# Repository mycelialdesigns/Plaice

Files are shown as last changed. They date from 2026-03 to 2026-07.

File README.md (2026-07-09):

# Plaice
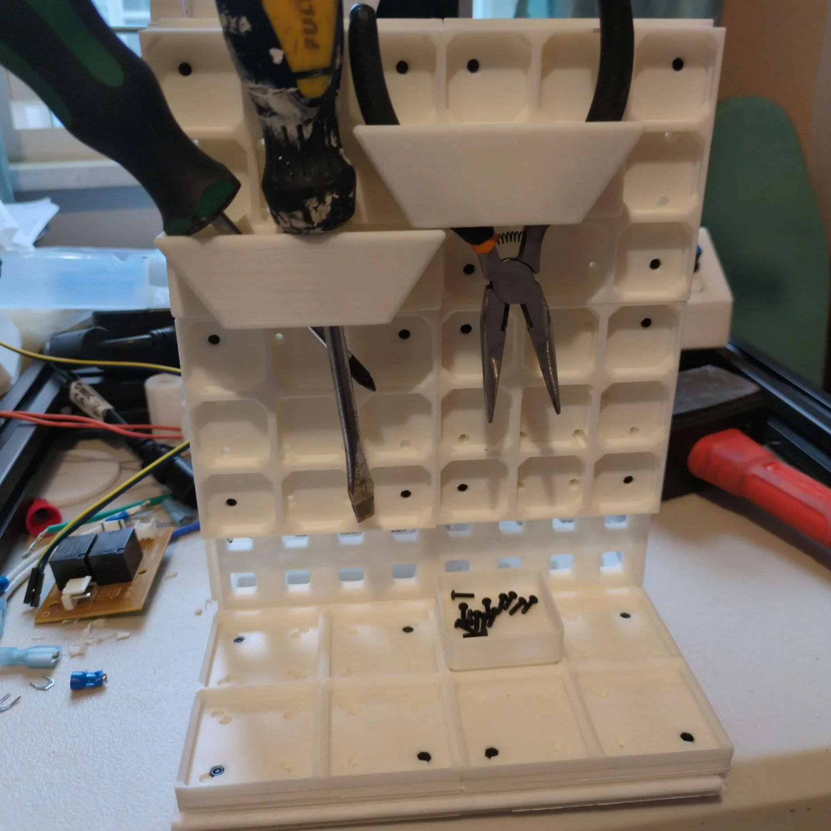
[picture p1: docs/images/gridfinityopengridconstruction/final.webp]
Gridfinity+OpenGrid Organizer
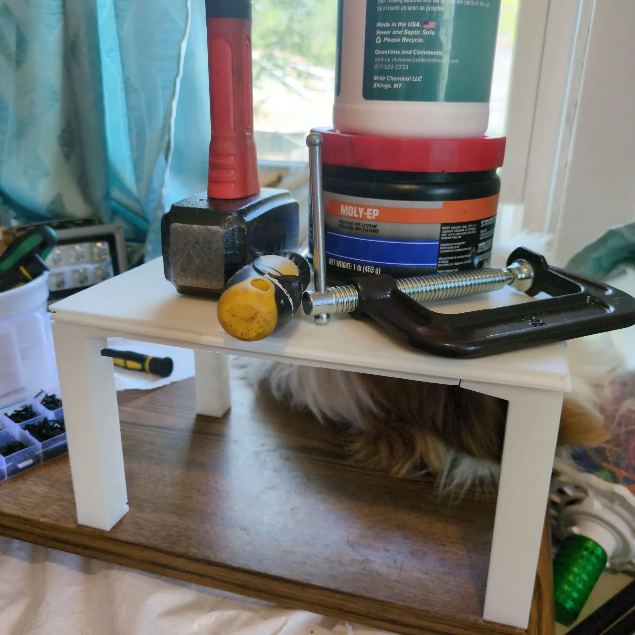
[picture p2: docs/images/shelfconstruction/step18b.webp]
Shelves
 

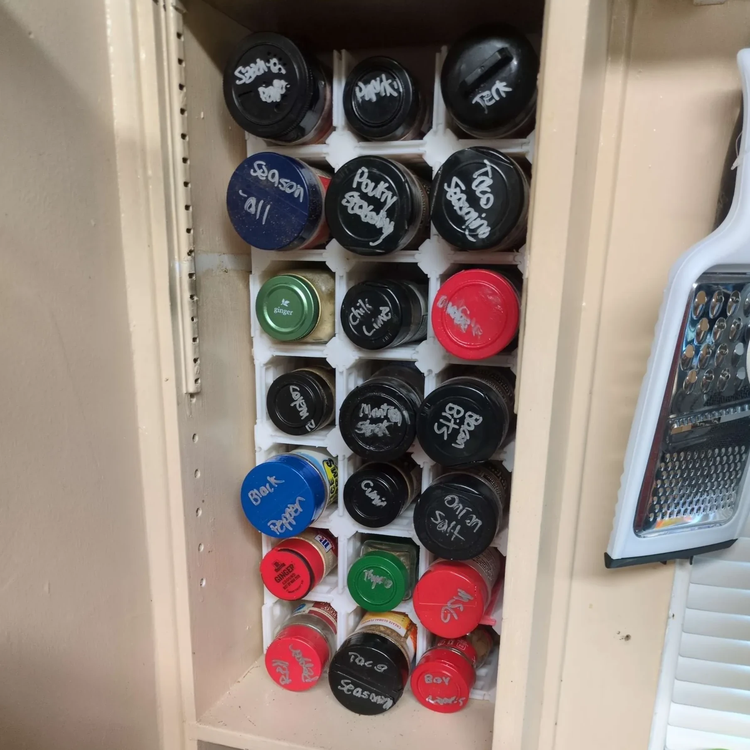
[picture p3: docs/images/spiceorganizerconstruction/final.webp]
Spice Organizer
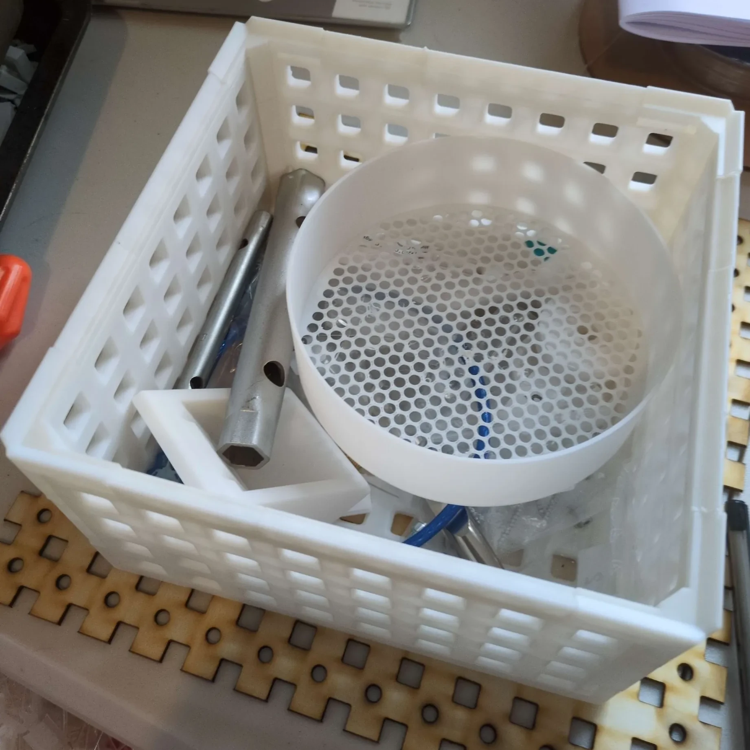
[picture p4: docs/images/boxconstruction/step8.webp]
Stacking Box
  

**_Print Once, Reconfigure as Your Space Evolves!_**

# What Is Plaice?
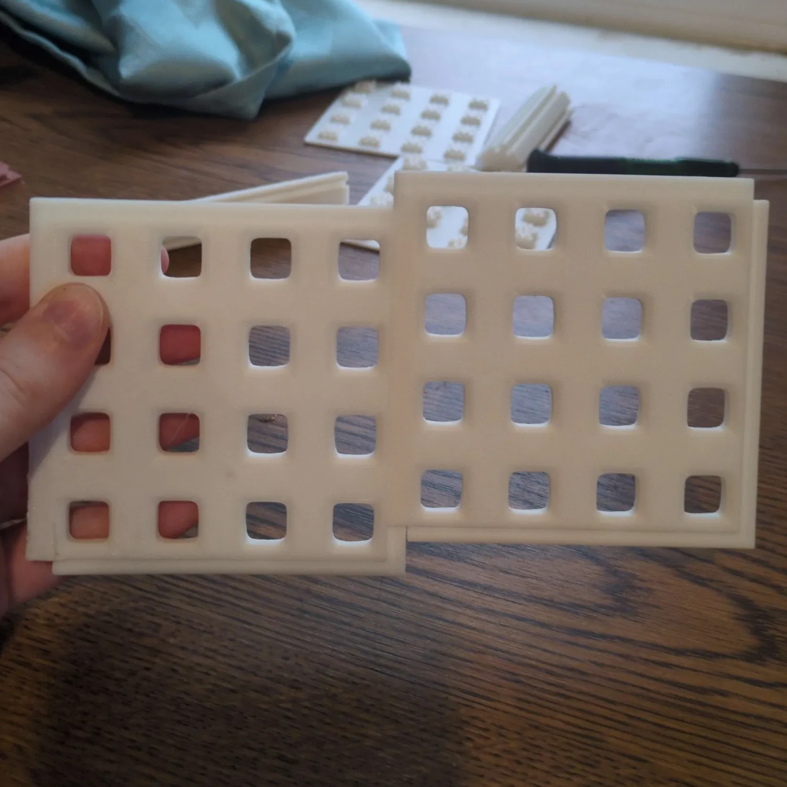
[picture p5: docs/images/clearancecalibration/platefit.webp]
Two plates slid together


Plaice is a 3d-printable modular construction system for living space organization. Unlike other similar
systems, Plaice enables radical free-form constructions out of basic structural elements called [_plates_](/docs/components/Plates.md),
which naturally slide together to allow for large assemblies to be built from smaller parts. Using just a few standard Plaice components,
it's possible to make:
- [Stacking Boxes](/docs/recipes/StackingBoxes.md)
- [Multi-tiered shelves](/docs/recipes/Shelves.md)
- [Spice Organizers](/docs/recipes/SpiceOrganizer.md)
- [Desktop Tool + Hardware Organizers](/docs/recipes/GridfinityOpenGrid.md)
- Drawers
- Hinged Clamshell Boxes
- Drawer Dividers

**_... among many, many more things!_**

Open, endlessly [remixable](/docs/design/InterfacingAndRemixing.md). Seamless compatibility with other systems
like [Gridfinity](/docs/components/GridfinityIntegration.md) and [OpenGrid](/docs/components/OpenGridIntegration.md). Plaice makes
your organization dreams a reality while allowing experimentation without waste through modular composition. 
Designed with simplicity and internal coherence in mind, Plaice stands out from similar "universal" organization
systems in its relatively small number thoughtful, carefully-engineered components.

_(Printing for most parts assumes settings for a .`4 mm` nozzle, two perimeters, and a layer height of `0.1 mm`. Most components will print without the need for slicer-generated supports, but check individual component pages for details.)_

**To get started with using Plaice**, first follow the [clearance calibration guide](/docs/recipes/ClearanceCalibration.md),
and then feel free to check out the other [recipes](/docs/recipes/Index.md).

---

### [Directory of all Plaice components](/docs/components/Index.md)

### [Directory of Plaice design articles](/docs/design/Index.md)

### [Contributor Guide](/CONTRIBUTING.md)

If you like this project, consider donating to the original creator at <https://paypal.me/MycelialDesigns>

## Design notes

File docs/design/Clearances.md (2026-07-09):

# Clearances
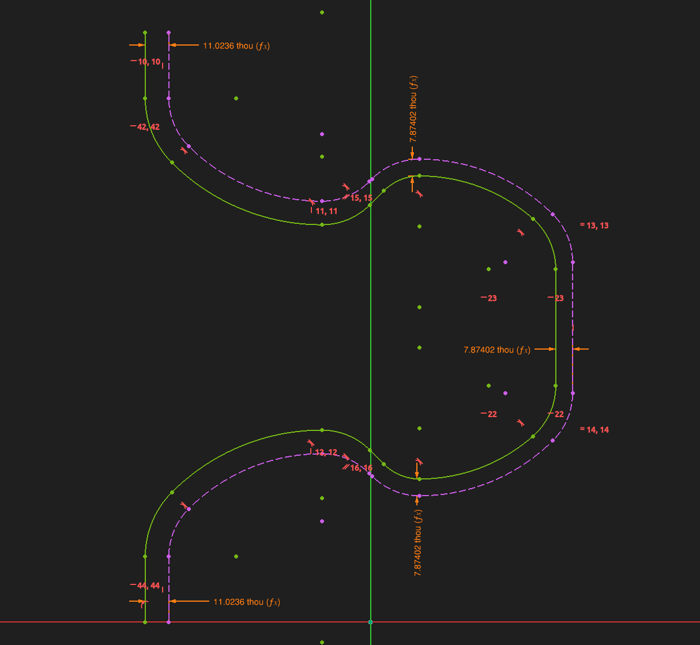
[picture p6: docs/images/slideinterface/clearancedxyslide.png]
Slide Interface, Clearanced For XY Printing
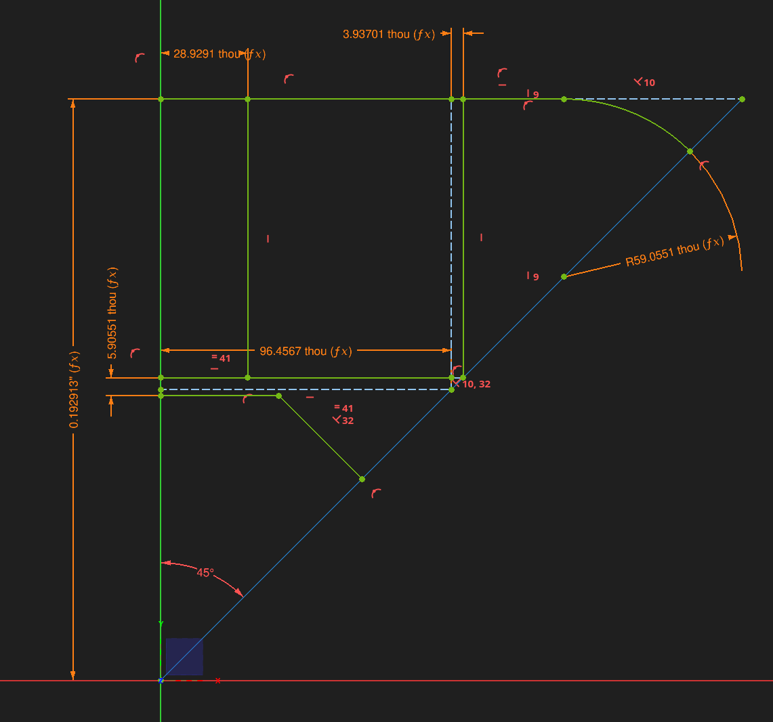
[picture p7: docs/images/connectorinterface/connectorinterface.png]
Connector Interface, Showing Tolerances
 

Designing Plaice components to fit together requires careful attention to the nominal clearances between components.

## Preliminary Definitions
Clearances describe the size of gaps between two surfaces so it's important to have a clear reference to what the surfaces
involved are. In our case, there are three different sources for relevant geometry to reference: "*interface*" geometry
which consists of 2D profiles in CAD expressing an idealized meeting-curve of two components, "*model*" component geometry which
represents the geometry expressed in 3D CAD and/or in exported .stl files, and "*de facto*" geometry which is the physical geometry
of real components after printing. 

## Print Bias Correction Clearances
Due to artifacts of the 3D printing process, de facto geometry will never exactly match model geometry. However, we have control
over the model geometry, which means that if we have systematic biases in how de facto geometry deviates from how we want it
to be, we can simply adjust the model geometry to compensate for those biases as best we can. The de facto geometry as we'd like it to
be is what we call *idealized* geometry, and it's essentially what we would get if we had a 3D printer with no printing artifacts whatsoever
and a layer height approaching zero (+ perfectly smooth). 

Consequently, our approach to creating modeling geometry can be kicked off by starting with the idealized geometry, and then introducing small tweaks
to the model geometry to correct for differences from the ideal which would occur when turned into de facto geometry via printing. These small tweaks
are all in the form of clearances applied between the idealized geometry and the modeling geometry at different locations throughout the model, and
so we call them *print correction clearances*. Typically, the additional clearance is applied where relevant to the geometry, and the surrounding
geometry has a smooth transition back to the uncorrected geometry where the corrections are not required.
It's important to note that these clearances are meant to be somewhat of a statistical average of the
clearance biases that they're meant to correct for across _all_ printed Plaice components, which says nothing of the variation, but we can simply
lump that in with other factors which determine our overall manufacturing tolerances.

### XY Hole Shrinkage Clearance
Slide Interface, Clearanced For XY Printing
When a 3d printer prints a circular arc in the XY plane, it deposits hot plastic centered along the arc which briefly
flows, then cools and hardens. Consider a simple model of this where the nozzle deposits plastic which falls in a region
bounded in XY by offsets of the arc, padded to the printing layer height. Also suppose that the volume of plastic deposited
on either side of the "nominal" arc that the nozzle follows is equal. Then, a direct consequence of these assumptions is that
the offset for the "interior" arc (smaller diameter) must be _larger_ than the offset for the "exterior" arc (larger diameter).

In other words, 3d-printed holes shrink along XY, with smaller 3d-printed holes systematically shrinking more than larger ones, and more
generally, any concave geometry along XY will expand inwards, with the amount of expansion dependent on curvature. While this effect
is not describable purely by a constant offset for _all_ radii of curvature, in practice, in Plaice, the curvatures of surfaces which
need an XY hole shrinkage clearance applied (mostly just [slides](/docs/design/SlideInterface.md)) are all pretty similar. We call the clearance value which issues
this modification to the design geometry over the idealized geometry the _XY Hole Shrinkage Clearance_. 

### Z Overhang Depression Clearance
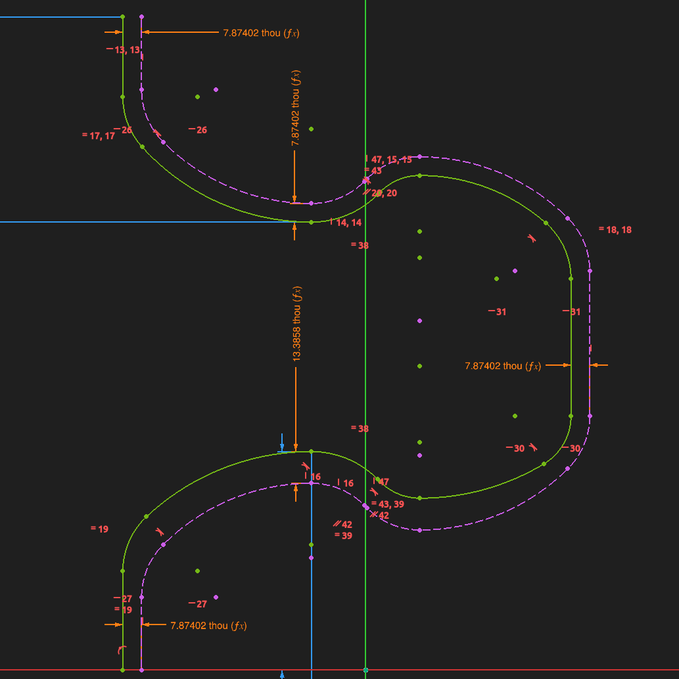
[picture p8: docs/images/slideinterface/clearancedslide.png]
Slide Interface, Clearanced For Z Printing

The overall process of 3D printing introduces some systematic errors which can make overhanging geometry depress along the Z axis toward the
build plate, both from physical causes and from the way that slicers interpret 3D designs. 

The single biggest physical cause has to do with
the fact that molten plastic will fall _down_ under the influence of gravity, and overhangs will tend to do the same unless cooled rapidly.
The same is true for _supported_ overhangs, because the support isn't completely solid, and may introduce bottom-surface roughness on removal.

To make matters worse, slicers determine what belongs on each layer "slice" of a model by intersecting the model with abstract planes which
are set to the height of the _top_ of the layer, not the middle, meaning that the effects of the semi-quantization induced by slicing will
cause overhanging geometry to shift _downwards_ by about half of a layer-height on average.

We cannot hope to model both factors exactly, but we can compensate by adding a clearance to "push up" any overhangs in the designs. We
call this applied clearance between the idealized and design geometry the _Z Overhang Depression Clearance_.

## The Clearance Multiplier
Print bias correction clearances aren't the only clearances we need to care about in the process of preparing Plaice components for printing.
Every 3D printer has its own quirks, and even when fully calibrated and printing geometry which corrects systematic printer biases,
individual 3d printers will still exhibit small variations in their output from print-to-print. 
Plaice components are designed to be printable by most 3d printers, and consequently, it's important that
we have some kind of mechanism for accommodating these dimensional variations. We do this by introducing additional clearances between mating parts
in a systematic way dependent upon how the parts are meant to mate. 

Plaice components like [plates](/docs/components/Plates.md) are highly dependent upon tight de facto clearances to minimize deflection in assemblies.
Simply choosing _one_ set of clearances intended for all printers would require us to select the _largest_ such clearance, which is
therefore unacceptable for our use-case. To resolve this problem, Plaice has a global _clearance multiplier_ which multiplies all non-print-bias-correcting
clearance values applied to design geometry. This multiplier is meant to be interpreted as approximately bounded below
by `1.0` (something intended for printers in the top 1% of print quality) and above by `1.75` (something which works for ~95% of all printers in the wild,
though it may wind up being a loose fit). 

## Clearance Levels
For .stl export of Plaice components, having a continuum of possible clearance multiplier values is untenable. To resolve this problem, we instead define
four clearance _levels_ for different values of the clearance multiplier, termed _Close_ for `1.0`, _Default_ for `1.25`, _Easy_ for `1.5`, and
_Forgiving_ for `1.75`. 

## Clearance Types
The "base" or "fundamental" clearance values which the clearance multiplier multiplies are assigned based on the intent behind mating geometry,
which falls into a small number of discrete categories we call "Clearance Types".

### Contact Fit Clearance
Applied to parts which are meant to assemble and _contact_ each other without substantial movement. Applicable to mating surface pairs where
assembly involves moving the surfaces toward each other, but also to mating surface pairs where the mating surface patches are small and/or compliant.
This is the tightest clearance type.

### Snug Slide Fit Clearance
Applied to mating surface pairs which have substantial contact surface area, and are meant to "slide" against each other, but only during
assembly.

### Smooth Slide Fit Clearance
Applied to mating surface pairs which have substantial contact surface area, but where the sliding between parts is meant to occur frequently
after assembly. This is the loosest clearance type.

## Tolerances
We mostly talked here about clearances instead of tolerances because most of the relevant tolerances to Plaice are actually one-sided tolerances
instead of symmetric tolerances. For example, for two [slides](/docs/design/SlideInterface.md) to fit together with _any_ other slides within
tolerance, they must have de facto geometry which never crosses the slide _interface_ which their idealized geometry is offset from. To bound the other side,
for each kind of interface, we do the simplest possible thing and declare that the idealized geometry with the maximum acceptable clearance multiplier is
the other surface defining the outer limit of the one-sided tolerance.

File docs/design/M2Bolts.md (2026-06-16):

# M2 Bolts
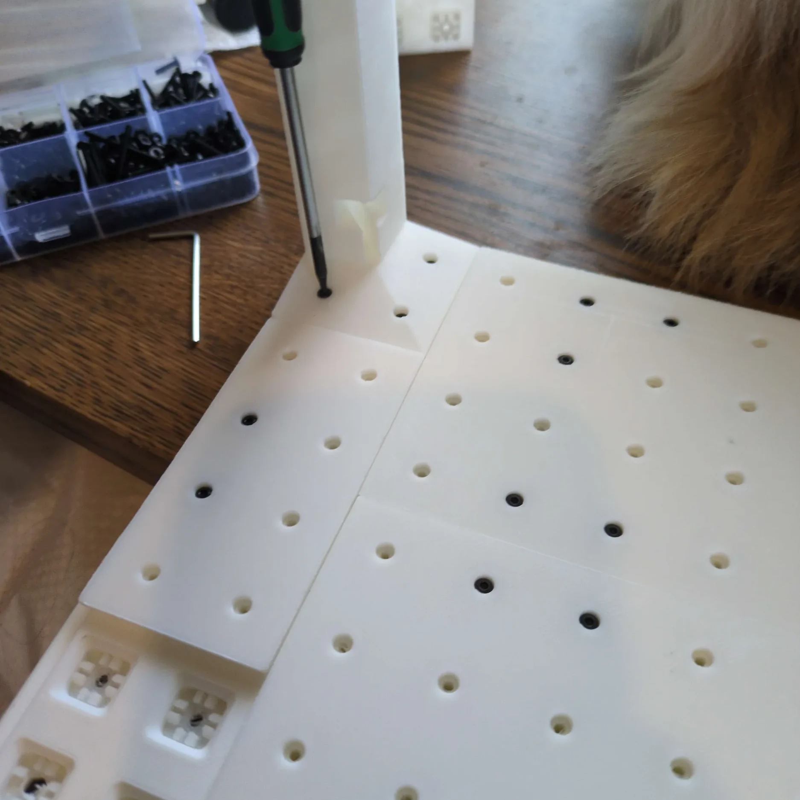
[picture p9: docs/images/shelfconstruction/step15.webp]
Nubbed covers secured on the bottom of a shelving unit


Plaice largely avoids the use of embedded hardware for the sake of rapid prototyping, but when it comes time to "cement" a design for a household organizer,
it can be advantageous to incorporate hardware for improving the strength of assemblies. (For a worked example of this,
see e.g: the [recipe for stacking shelves](/docs/recipes/Shelves.md)). Additionally, Plaice leverages hardware in
situations where printing a single part could be suboptimal in [bolt-on components](/docs/components/BoltOnComponents.md).

## Required Lengths
M2 hardware is employed in Plaice, and it's strongly recommended you buy a kit
of bolts which (at least) includes `4 mm`, `6 mm`, `10 mm`, `12 mm`, and `16 mm` lengths.

The following is a handy guide
to what lengths of M2 bolts are required for various scenarios.

### Corner Caps

[Corner caps](/docs/components/CornerCaps.md) are composed of two separate pieces which are meant to be connected
together with a `6 mm` M2 bolt.

### Backings onto Bolt-ons

To use bolt-on components in the most straightforward way, where they
are simply bolted on to a Plaice [backing](/docs/components/Backings.md) which provides
[connectors](/docs/components/ClipInterface.md), M2 nuts must be slid into the backing.
In this case, the following lengths of M2 bolts are inserted from the bolt-on side:

| | Nubbed Backing | Clipped Backing |
|--|:--:|:--:|
| **Bolt-On** | `4 mm` | `6 mm` |

### Bolt-ons, Nubbed and Clipped Connectors

Beyond the case of backing bolt-on components, M2 hardware can be employed in Plaice
to secure connections which would otherwise be accomplished purely through clip/nub connections. This attatchement provides more resistance to pull-out and some degree of preload. For example, Plaice clipped [covers](/docs/components/Covers.md)
may be attached to nubbed covers and secured with `6 mm` M2 bolts (together with captive M2 nuts).
We can generalize that rule to other components with clipped and nubbed connectors:
e.g: a nubbed [plug](/docs/components/Plugs.md) attached to a clipped plug _also_ can be secured with `6 mm` M2 bolts.

But clipped and nubbed connectors aren't the only things that can be on opposite ends (bolt head and nut end) of
a M2 bolt -- Bolt-on components atop backings may be at either of the ends. In these
situations, a single bolt should go through
end-to-end. In tabular form, here are the required lengths of bolts for every combination of two "ends":

| | Bolt-On  | Nubbed Connector | Clipped Connector |
|--|:--:|:--:|:--:|
| **Bolt-On** | `16 mm` | `10 mm`  | `12 mm` |
| **Nubbed Connector** | `10 mm` | -  | `6 mm` |
| **Clipped Connector** | `12 mm`  | `6 mm`  | - |

### Thru-Nubs

In a Plaice assembly involving thru-nubs, the required M2 bolt lengths may be derived from the table in the
previous section by adding `7 mm` (`1 HU`) for each (possibly chained) thru-nub, and then rounding up
to the nearest multiple of `2 mm`. This rounding is not _ strictly required_ if you have readily available bolts
 with the required dimensions, but M2 bolts 
in `2 mm`-multiple lengths are generally more likely to be stocked in stores. 

One particular case of this is worth calling out due to its frequency:
When connecting **two beams** (as one would for [building stacking shelves](/docs/recipes/Shelves.md)),
a nubbed connector from the top of one beam attaches to a thru-nub which then attaches to the
clipped connector at the bottom of the next tier's beam. From the table above, the base length
is then `6 mm`, and so `+ 7 mm = 13 mm`, or rounded, **`14 mm`**.

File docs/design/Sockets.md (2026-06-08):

# Sockets

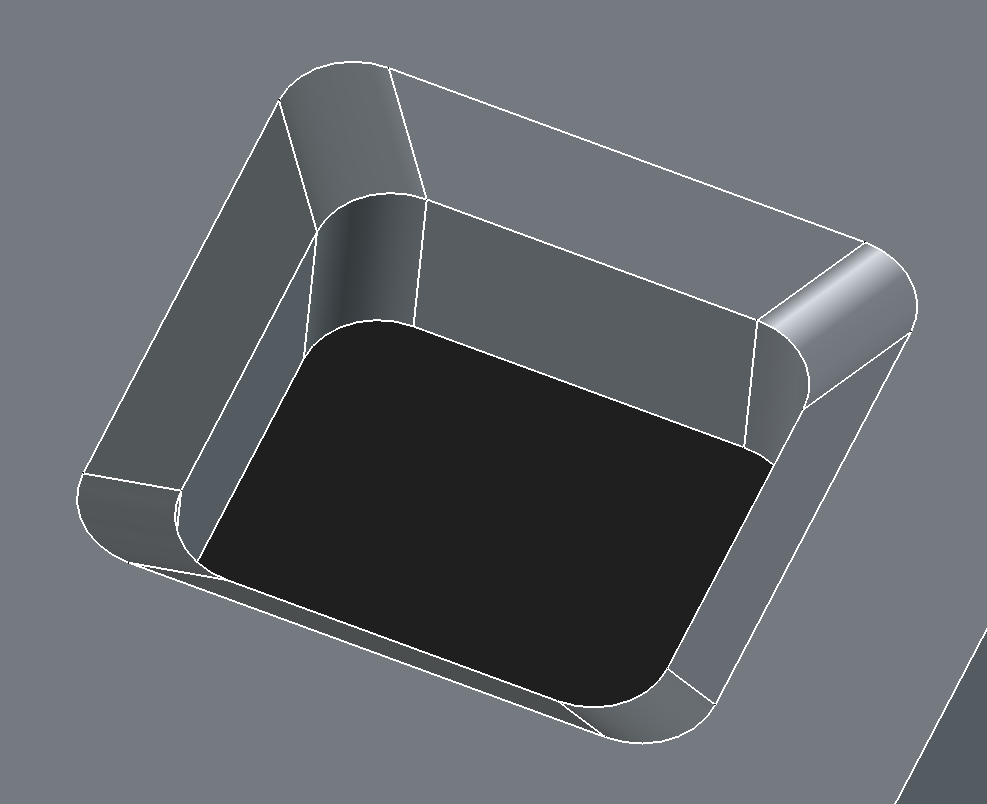
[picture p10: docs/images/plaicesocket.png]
A Plaice Socket
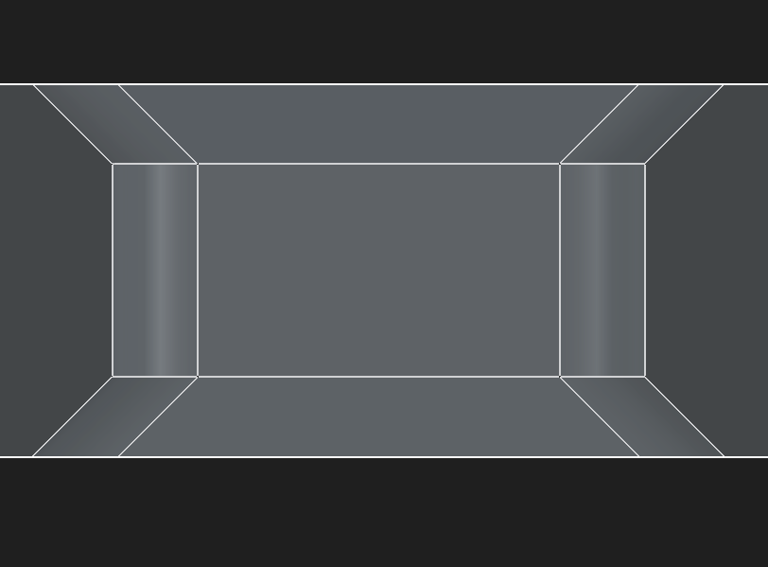
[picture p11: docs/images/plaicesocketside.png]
A Plaice Socket, Side View (See-Thru)


Plaice _Sockets_ are chamfered rounded-square voids which allow the insertion of Plaice [clipped and nubbed connectors](/docs/design/ClipInterface.md).
They have a [`1 HU`](/docs/design/Units.md) depth, with the leading `2 x 1.5 mm` devoted to 45-degree chamfered sections on each side. The remaining `4 mm` has a cross-section of
a rounded `10 mm` square with a corner fillet (radius of `1.6 mm`). 

## Strength and Deflection

Intuitively, since a Plaice [plate](/docs/components/Plates.md) is a slab with sockets cut out of it, the plate's strength heavily depends
on the socket dimensions. The deflection of a Plaice plate with sockets is roughly two times what the deflection of
what a solid plate would experience under a one-sided load, and around the de facto socket dimensions, FEM verifies that the deflection is roughly linear
in the socket width. Consequently, Plaice sockets are the smallest dimensions that they can be while maintaining the functionality
of socket connectors. 

## Print Correction Clearances

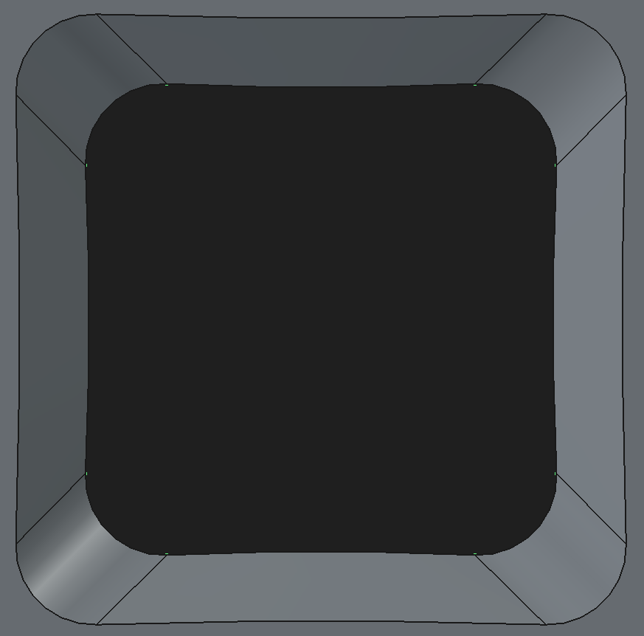
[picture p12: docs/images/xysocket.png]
A Plaice Socket, Corrected for XY Printing


When a socket is printed oriented along the XY plane, the internal radius shrinkage [print correction clearance](/docs/design/Clearances.md) applies, and so the modeled
CAD geometry needs to have larger fillet radii in the socket corners. However, the straight sides of the CAD geometry don't have an associated correction to apply!
Empirically, it appears to be the case that uncorrected sockets print with a slight mensicus shape along those nominally straight walls, almost as if they're "smoothing"
out the radius shrinkage correction from the filleted corners. To correct for this, the CAD geometry for XY sockets replaces the straight segments with arcs which
are constrained to be tangent with the (enlarged) corner fillets and also with the centers of each segment.

## Manufacturability

Sockets are explicitly designed to be manufacturable via subtractive manufacturing (routing). This is the reason for the corner fillets, as well as the particular
way that the socket is chamfered. The radius of the corner fillet does not change along the chamfer, which allows the fillet to be cut more cleanly
and efficiently by a single straight bit than if a changing fillet radius were used. The radius of the fillet is set so that a 1/8" diameter routing bit (US units)
could be used to cut sockets. The chamfer having a length smaller than the fillet radius also means that the chamfer can _also_ be cut smoothly using a 90-degree
V-carve bit, if desired.

Furthermore, the chamfer length's value of `1.5 mm` has direct implications for laser cutting, since `1.5 mm` wood veneers are not difficult to come by. While 3d printing
is still necessary in such a set-up to provide inserts for the chamfers, this dimensioning makes the approach viable.

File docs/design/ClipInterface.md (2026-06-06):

# Clipped and Nubbed Connectors
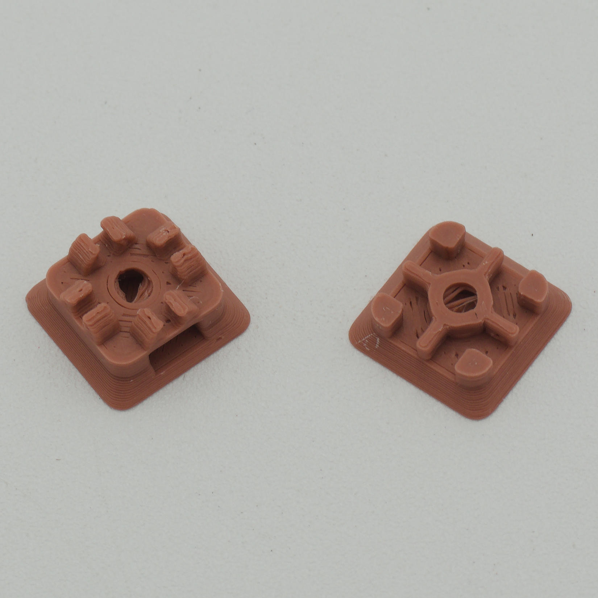
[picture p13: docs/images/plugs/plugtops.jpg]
Plugs, Clipped and Nubbed
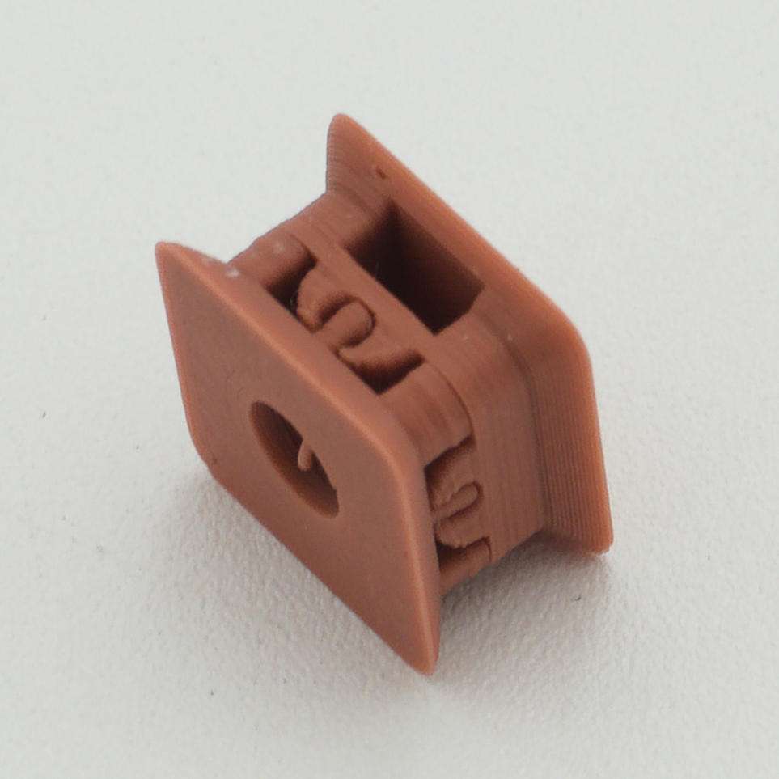
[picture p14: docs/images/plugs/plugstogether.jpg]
Plugs, Clipped and Nubbed Connected
 

Clipped and nubbed connector pairs provide a way to connect two Plaice components, most frequently inside of a Plaice [socket](/docs/design/Sockets.md).
They are "snap" (compliant) connectors where the four clips of a "clipped" connector grabs on to the four nubs of a "nubbed" connector,
preventing movement between the two halves unless the connection is undone through applied force to separate them. 

## Geometry

Connector interface, 1/8 of the top-down schematic

Clipped and nubbed connectors have a rounded square footprint which fits inside
of Plaice sockets. Both types of connectors share the same four-fold rotational symmetry about their center, with the eponymus "clips"
and "nubs" arranged along the edges of the rounded square base. For clipped connectors, that's all there is to the top-down layout,
but for nubbed connectors, there is additionally a central octagonal island and four corner islands. 

### Clip geometry
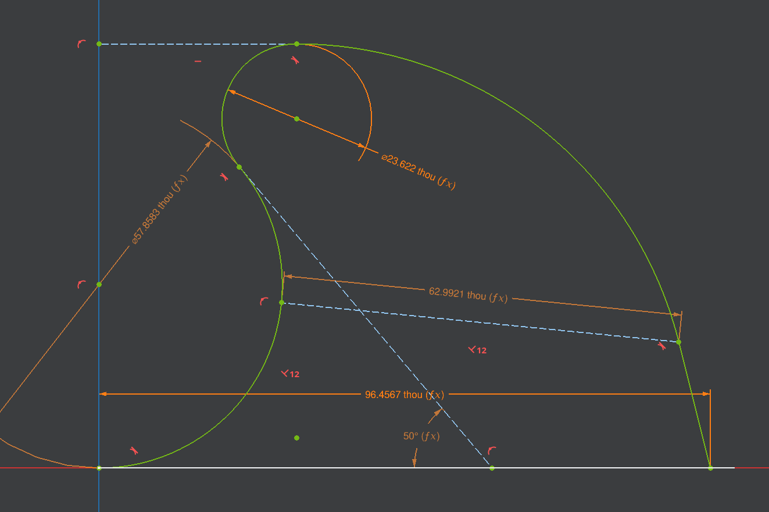
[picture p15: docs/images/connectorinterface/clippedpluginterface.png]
1/2 of a clip profile


The geometry of the clips is very carefully engineered for their small `~5.0 mm x ~2.3 mm` footprint to ensure that they won't break
under typical use (and then some). The clip prongs are tapered in such a way that it does not take many layers from
the tips of the clips to reach a width which is able to pack in two external perimeters, which allows the profile to mostly
behave like a bulk material. The profile of a clip prong is made of three arcs, one for the clip center, one for the tip of
the prong, and another for the outside envelope of the clip, with a line segment completing the connection to the base.
The top arc is constrained by a minimum size to allow for the 3d-printed clip prong tip to more smoothly slide against a paired
nub, and the angle of closure of the interior arc is also set to help the prong tip move out of the way when a nub is inserted.
The central arc's radius is maximized to spread out stresses encountered when the clip is bent, but the outer arc's geometry
(+ line segment) is largely set up for achieving the maximum number of perimeters as quickly as possible, since FEM results
indicate that stress does not tend to concentrate there. 

#### Clip FEM
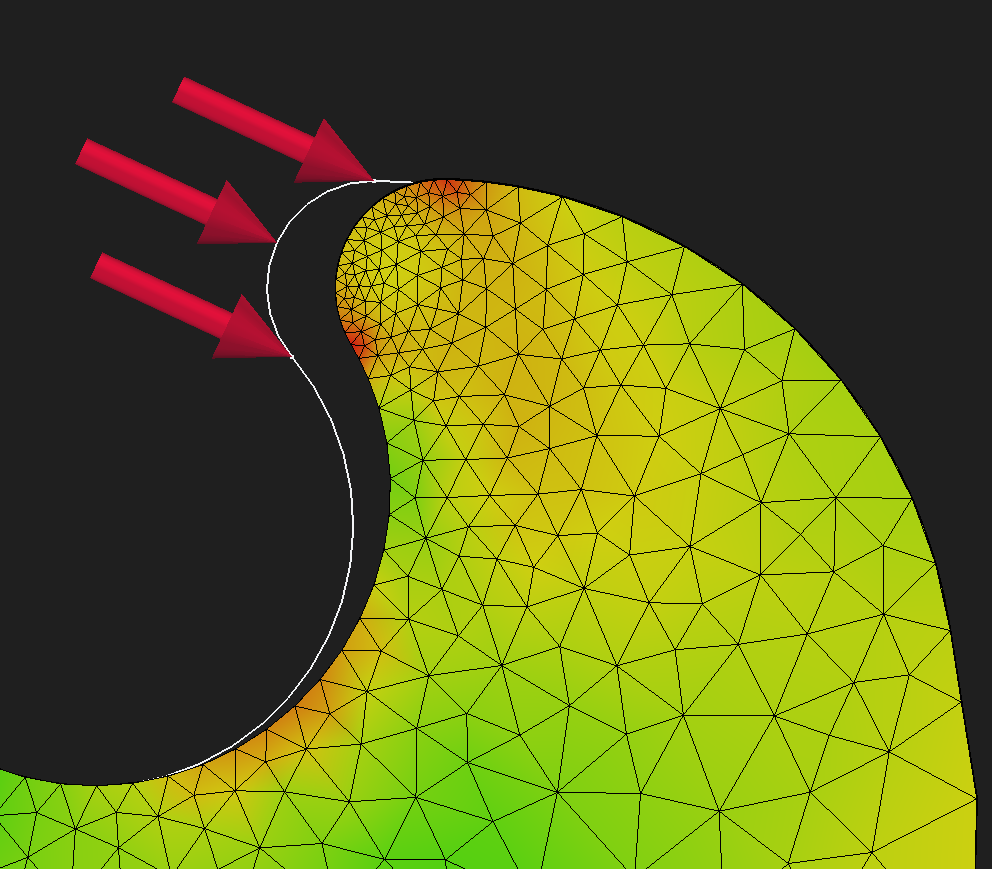
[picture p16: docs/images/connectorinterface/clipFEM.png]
FEM on a Clip w/ heatmap of Frobenius norm of strain tensor


To ensure that the compliant clips stay functional after repeated use, a finite element analysis of the strains experienced
by the clip when bent allows for optimization of the clip design. Additionally, for the clip geometry
as defined above, to bound the value of the base width of the clip, it's necessary to simulate what happens when the clip is deformed
during connection to ensure that the clip prongs never have any part of them extend beyond the base footprint, because it would cause
interference with the four corners of the paired nubbed connector.

To analyze the results of the FEM, unlike the situation with the [slide interface FEM](/docs/design/SlideInterface.md), the stresses experienced by the
clip during connection are transient. Consequently, a static analysis like what was implemented in FreeCAD for this will not
tell the whole picture, but we can still gain some insights. In particular, we are interested in the
strain experienced by the clip when bent to its "open" position, and want to minimize the maximum principal strain. Unfortunately,
FreeCAD has no built-in expression for principal strain, and finding principal strain using a component-based closed formula is fairly
unwieldy. However, we _can_ input a formula for the Frobenius norm of the strain tensor, which allows us to indirectly bound the
principal strain. 

### Nub Geometry
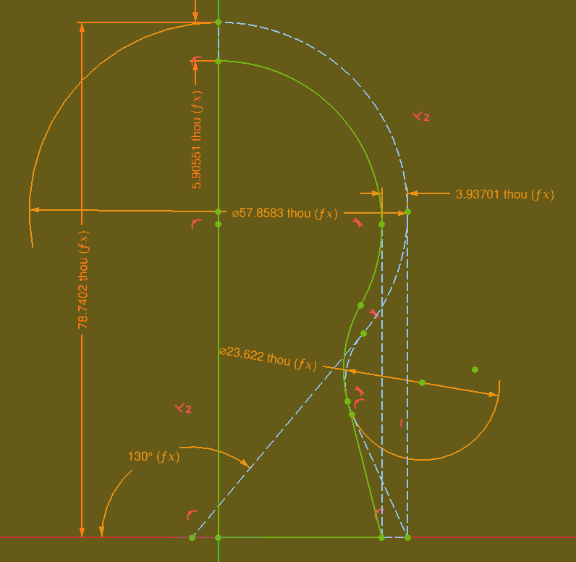
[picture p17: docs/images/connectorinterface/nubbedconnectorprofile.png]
1/2 of a nub profile


For the most part, the geometry of nubs is the inverse of that of clips, but the bottom of the nub is modified to connect
to the connector base with a straight line as opposed to an arc. This nub base is set up in such a way that the bottom of the nub
has exactly the same width as its maximum width up above. This is done to give extra clearance to the tips of connected
clips (to handle deformations under load), and also to create a clean visual transition to the seam with the central octagonal island.

## Clearances

For the top-down footprint, most clearances from the top-down "interface" profile are set to the generic "contact" clearance, since the
mating surface area is fairly small, and it's structurally important to prevent relative rotation of the connectors as much as possible.
However, there are some exceptions -- in particular, the central octagonal island on the nubbed connector is given more clearance from
the interface bounds, because the central island is not meant to engage with anything else, and is simply there to serve as a sheath
for inserted M2 bolts. 

The side profiles of the nub and the clip provide their own special cases. For the clip profile, no clearances whatsoever are applied,
because the clip is compliant, and having fixed geometry also greatly simplifies the analysis of the clip's strength. The nub does
have clearances applied, but with a larger clearance at the tip of the nub which gradually works its way toward tangency with the interface
as the profile approaches the point of contact with the clip tip. Once again, this is done because the clip is compliant, and so
the required clearance drops closer to the clip's tip.

Vertical clearance between paired connectors is set to seat at the "snug" slide-fit clearance. This is somewhat larger than the contact
fit clearance to ensure that the connectors will tend to have a small gap between them when assembled with plugs on opposing sides of a
Plaice socket. The gap allows for a bit of pre-load to be generated by tightened [M2 bolts](/docs/design/M2Bolts.md), if desired. Additionally, the gap allows for Plaice sockets
to have somewhat looser tolerances on their chamfers given the relaxed seating of connectors, especially since this is made bidirectional
through the fact that a clip can engage with a nub and still have some retaining force even if not fully inserted.

## Relation to Sockets

Clipped and nubbed connectors are designed to fit inside of Plaice sockets, but the height of the connectors is only half (`2.0 mm`) of the
central portion of a Plaice socket (`4.0 mm`), and so at first, it would seem like we're leaving extra space on the table. Even stranger,
clipped connectors in Plaice typically sit atop a `2.0 mm` rounded square pad, but nubbed connectors don't have this! What gives?

There are two primary reasons for this apparent asymmetry, and both are related to how the system can accommodate alternative
types of connections which don't rely upon the clip-and-nub geometry. First, the `2.0 mm` rounded square pad provides valuable
space for the clipped connectors to be able to accommodate a captive M2 nut, which would be virtually impossible without it.
Second, it allows "stub" connectors consisting just of a `2.0 mm` rounded square pad on a plug to mate with a nubbed plug.
While that may not seem useful at first, it does open the door to the possibility of _routed_ Plaice components
which would otherwise need clipped connectors. While the current iteration of this specification doesn't include it,
future iterations should.

There's another, more subtle, more structural reason. The positioning of the clips on the clipped connectors and the corner islands on the nubbed connectors is such that
they make contact with an enclosing socket, preventing rotation. Consequently, they are made to be as thick as they possibly can
be considering the limited footprint of the connectors, applied clearances, and other objectives and constraints related to clip
geometry. Even after all that, the clip (being compliant) is still a seeming target for accidental breakage.
However, in the case of the clip geometry, the aforementioned `2.0 mm` rounded square pad helps to ensure that the clip
itself does not bear the brunt of the torque-induced stresses when inserted into a socket.

## Standard Orientation

By default, when considering horizontal Plaice [plates](/docs/components/Plates.md), it's typical to assume that the top side of the plate is for inserting clipped connectors,
and the bottom half is where components with nubbed connectors get inserted. The reasoning for this is based upon the geometry of [beams](/docs/components/Beams.md):
The bottom of a beam needs to be able to sit flat on a surface. Consequently, the bottom of a beam cannot protrude, as would be required
for a nubbed connector to reach the correct mating depth, and so it instead has a clipped connector embedded in a socket at the bottom and a nubbed
connector on top. Consistency with beam orientation is important for shelves, because it determines what can be mounted to the top surface of the shelf,
and generally, that includes all sorts of things, like [Gridfinity baseplates](/docs/components/GridfinityIntegration.md).
Conversely, the bottom side of a Plaice plate is a good place for e.g: Gridfinity mounts by analogous reasoning.

## M2 Bolt Usage
Clipped connectors typically have a channel on their side for the insertion of a M2 hex nut. When fully inserted, the nut is held
captive against some backing walls, preventing rotation. A hole on the front face of the clipped connector allows access to the
nut from external [M2 bolts](/docs/design/M2Bolts.md). 

Conversely, nubbed connectors make some provision for an M2 bolt to be inserted through their back face, with the shaft of the
bolt coming through a hole on the front face.

When the two halves are connected together via an M2 bolt/nut pair, the snap effectively cannot be separated unless the
M2 connection is undone, which can have many practical structural purposes in Plaice assemblies. At the same time, it is important
to realize that adding M2s is not a silver bullet -- an assembly can still be structurally weak even if all snaps have M2s.

## Printability Modifications
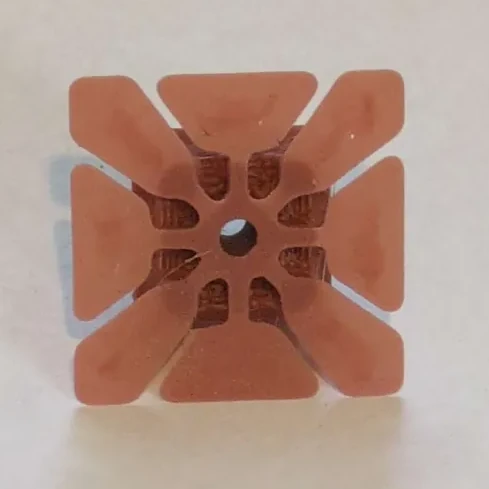
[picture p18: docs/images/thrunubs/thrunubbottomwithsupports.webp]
Thru-nub Bottom, Showing Mouse Ears
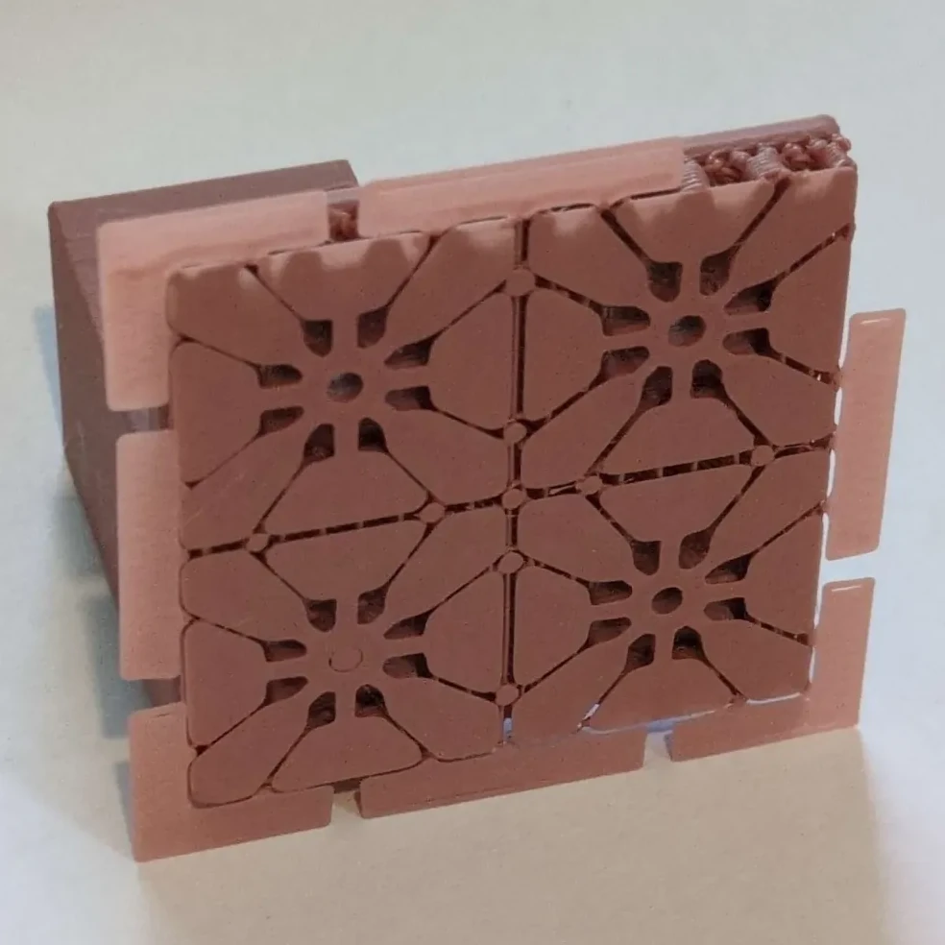
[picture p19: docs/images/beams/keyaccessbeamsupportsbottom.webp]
Key-access beam, showing supports on bottom
 

The print orientation of clipped and nubbed connectors is almost always such that their front and back faces align with the +-Z
printer axis, because typically they are printed in arrays on Plaice components which are intended to affix the component
to a Plaice plate, and so it generally makes sense to align the XY printer plane and the plane of these arrays. However,
this raises a problem for components (e.g: [thru-nubs](/docs/components/ThruNub.md), [beams](/docs/components/Beams.md)) which have clip or nub connectors on opposing sides:
Which connector should be on the bottom (and consequently, require some support and/or support removal, and possibly experience
some surface deformations due to sagging), and which should be on the top? Intuition would say that the clipped connector
is more intricate, and with more delicate features (compliant clips), and so it should belong on top.

Consequently, it's worthwhile to consider ways to "bake in" support structures for nubbed connectors oriented facing downwards
on the print bed to improve print quality, first layer adhesion, and the ease of support removal. Luckily, the geometry
of the nubbed connector makes it relatively easy to do so. Assuming that the tips of the nubs and all four corners have
good bed adhesion, bridging between them is a piece of cake given the involved dimensions. However, by default, they
don't have good bed adhesion. To improve this, an eight-petaled contiguous shape is formed on the first layer
to provide "mouse ears" for the first layer. This dramatically improves adhesion, and consequently
allows nubbed connectors to be printed upside-down without generated support structures.

There is no such similar printability modification for clipped connectors. This is for two primary reasons:
Firstly, due to the printability modification for nubbed connectors, the same kind of modification for clipped
connectors is largely unnecessary, since it results in the face of most clipped connectors facing upwards (+Z)
in print orientation. Secondly, the geometry of the clip connectors would require support structures to be
generated at the four corners of its layout, because unlike nubbed connectors, there is nothing in the corners on
the bottom printed layers for the base of the connector to bridge from. While that problem isn't insurmountable,
its inconvenience and low probability of use mean that it is currently unimplemented in Plaice.

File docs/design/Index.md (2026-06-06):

# Design Index

## [Bolt-on Components](/docs/design/BoltOnComponents.md)
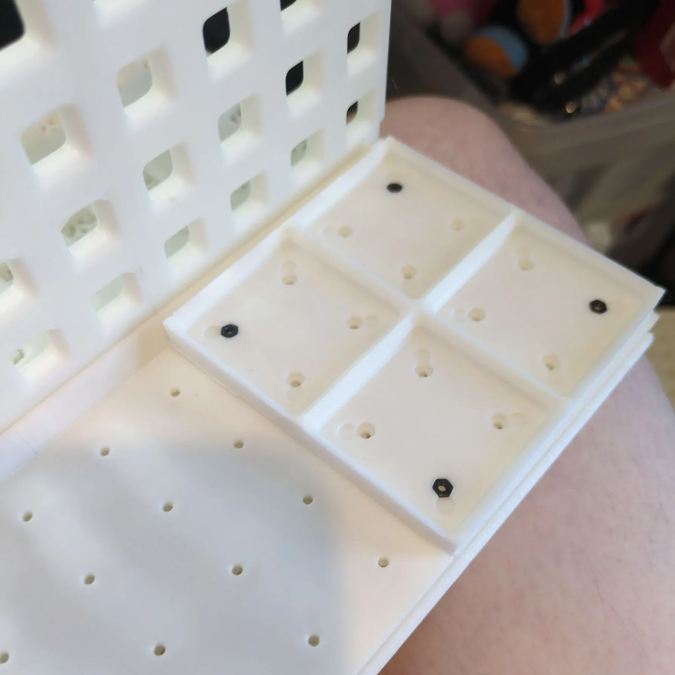
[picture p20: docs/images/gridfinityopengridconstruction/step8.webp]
A gridfinity bolt-on in the process of being secured to a clipped backing


## [Clearances](/docs/design/Clearances.md)
Slide Interface, Clearanced For XY Printing Connector Interface, Showing Tolerances

## [Clip Interface](/docs/design/ClipInterface.md)
Plugs, Clipped and Nubbed Plugs, Clipped and Nubbed Connected

## [Interfacing, Remixing and Licensing](/docs/design/InterfacingAndRemixing.md)

## [M2 Bolts](/docs/design/M2Bolts.md)
Nubbed covers secured on the bottom of a shelving unit

## [Slide Interface](/docs/design/SlideInterface.md)
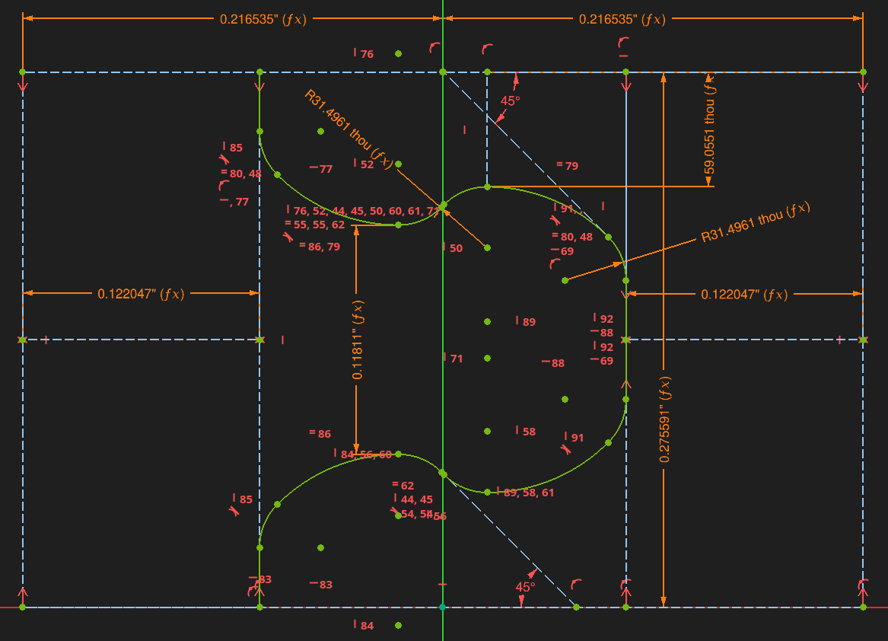
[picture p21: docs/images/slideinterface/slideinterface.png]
Slide Interface


## [Sockets](/docs/design/Sockets.md)
A Plaice SocketA Plaice Socket, Side View (See-Thru)

## [Units](/docs/design/Units.md)
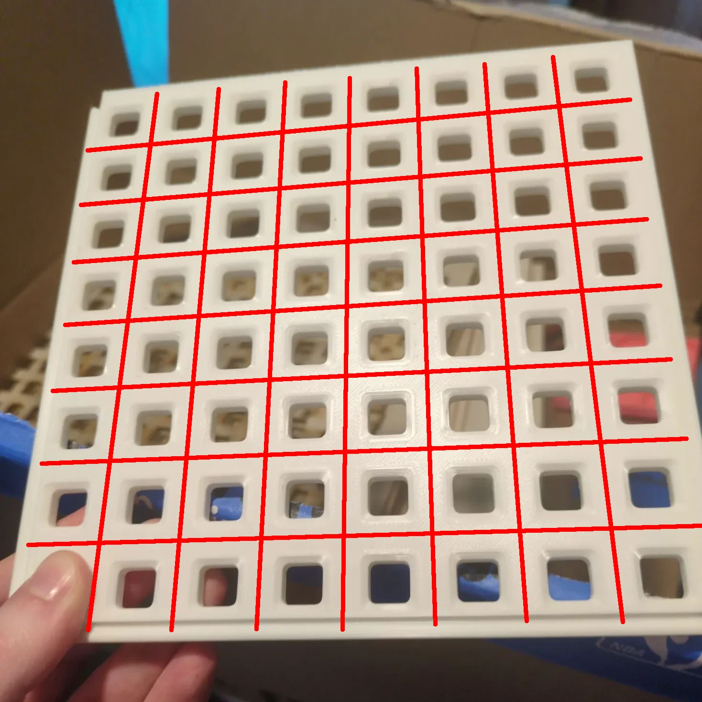
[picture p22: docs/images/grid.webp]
Plaice Plate Annotated with Cell Grid
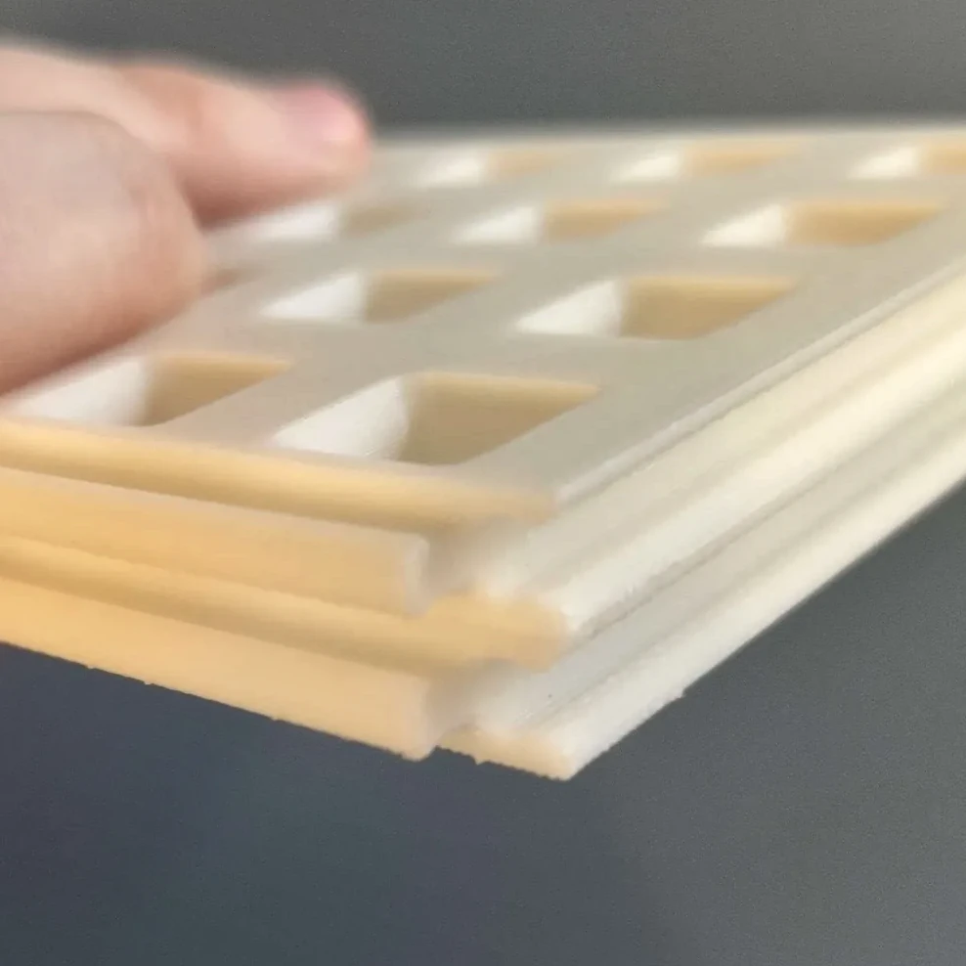
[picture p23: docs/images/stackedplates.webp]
Two Plaice plates, stacked


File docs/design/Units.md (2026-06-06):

# Units
Plaice Plate Annotated with Cell Grid Two Plaice plates, stacked

Any modular constuction system is faced with the fundamental problem of defining how the system
will sit in 3D space, and Plaice is no exception. Systems like [Ikea SKADIS](https://www.ikea.com/us/en/cat/skadis-series-37813/), 
[HSW](https://www.printables.com/model/152592-honeycomb-storage-wall), and [OpenGrid](https://www.opengrid.world/) are
two-dimensional mounting systems, which Plaice also provides as a sub-system.
That said, Plaice has more similarities with three-dimensional grid-based systems like [Gridfinity](https://gridfinity.xyz/) and `8 mm` stud systems ([MegaBloks](https://themegabloks.com/), [LEGO](https://www.lego.com/)). 
Unlike those systems, Plaice [plates](/docs/components/Plates.md) may occur oriented parallel
to any axis-aligned plane -- there is no "preferred" orientation for components of the system
(like how Gridfinity bins are always oriented "right-side-up"), even if there is a direction
(Z) which goes with gravity. While we could explain the dimensional unit system from an absolute
frame of reference (with plenty of reference to "quarter height-units" and rotational symmetries),
it's much simpler in practice to examine frames of reference taken relative to the orientation
of a Plaice plate that we intend to focus on. By convention, we take the [socket](/docs/design/Sockets.md) grid
to coincide with the XY plane when considering this plate-relative reference frame.

## Cell Units (CU)
Plaice Plate Annotated with Cell Grid

Along the XY plane, a Plaice plate is made of repeating square units known as _cells_. Each cell has a socket
placed squarely in the middle, and when projected onto the XY plane, each cell measures `21 mm x 21 mm`. Due to the centrality
of Plaice plates to the system, a length of 21mm is known as a **Cell Unit** (CU). Plaice plates are typically denoted by their
width and length in cell units, e.g: `2 x 4`, `4 x 4`, `8 x 8`, etc.

### Interoperability 

The size of a unit cell has massive implications for how easy or difficult it is to integrate
Plaice with other modular construction systems in a bidirectional manner. In particular, the `21 mm` "Cell Unit" length was chosen
for ease of integrating with [Gridfinity](/docs/components/GridfinityIntegration.md) (1:2 ratio in each side length for a unit cell)
and [OpenGrid](/docs/components/OpenGridIntegration.md) (4:3 ratio), as these are two of the most widely-used 3d-printed modular construction systems.
If two systems have unit cells of lengths `a` and `b`, then
the total length it takes for the two systems to "sync up" at a shared unit-cell boundary is given by their least-common-multiple, `lcm(a, b)`. 

Such synchronization (within a reasonable (read: printable!) length) is arguably a _requirement_ for a good bidirectional integration
because it takes any guesswork out of the systems' relative alignment. However, if we consider instead _unidiectional_
integations, where one system is used "in the large" and the other is used "in the small" (e.g: the user primarily uses system A,
but there are tiny pockets adapted locally to system B), there is no longer any such
requirement for strict synchronization, because portions that use the "smaller" system can simply give up some margin to be able to synchronize with system A again.
Such a strategy could be used to integrate Plaice as the "smaller" system relative to [Multiboard](https://multibuild.io/) and other systems for which
bidirectional integrations would be unwieldy. At the time of writing, no such unidirectional integrations have been implemented.

## Height Units (HU)
Two Plaice plates, stacked

Along the Z axis, a Plaice plate is `7 mm` thick. A distance of `7 mm` is known as a **Height Unit** (HU), and it also appears frequently in Plaice
definitions. This value is identical to a Gridfinity "height unit", though largely by coincidence. From divisibility principles mentioned in the previous section,
and due to the potentially-arbitrary orientation of Plaice plates in space, the thickness of a Plaice plate should evenly divide a grid unit. 21=7*3, and 3mm
is far too thin, so 7mm it is. 

3 HU being equal to 1 CU is exploited constantly in the design of Plaice components, since a plate placed on its side standing in the (lateral) "center" of a cell
then has exactly 1HU on each side of it as margin to the adjacent cells on the baseplate. For examples, see [corners](/docs/components/Corners.md),
[crosses and tees](/docs/components/CrossesAndTees.md), and [slide clips](/docs/components/SlideClips.md). 

## Fractional Units

If you read between the lines of the previous section and the symmetries of Plaice [slides](/docs/design/SlideInterface.md), you can deduce that
half of a height unit is an occasionally important quantity when discussing Plaice. Additionally, an even smaller fraction of a height unit, `.25 HU`,
is invoked for Plaice [covers](/docs/components/Covers.md).

## Base-2 Radix

To minimize the effects of tolerance stack-up and cumulative deflection, Plaice plates typically are only made with power-of-two grid-unit widths and lengths.
Any length and width of composite plate may be obtained by sliding Plaice plates together (optionally stabilising them against deflection using paired covers),
and obtainabile within a number of Plaice plates which is asymptotically logarithmic in the demanded dimensions.

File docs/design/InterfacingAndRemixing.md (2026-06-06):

# Interfacing, Remixing, and Licensing

Plaice is an open ecosystem where anyone with 3d modeling experience can contribute.
Beyond that, it is intended to be an ecosystem which inspires a culture of remixing and shared learning.

## Licensing

To support these goals, Plaice employs two separate licenses to different kinds of artifacts: the 
[CERN-OHL-S](/LICENSE-cern_ohl_s_v2.txt) to all CAD files, and [CC-BY-SA](LICENSE-cc-by-sa-4_0.txt) to everything else in this repository and its associated exports,
including 3d model files. 

The OHL-S is a "strongly reciprocal" license, meaning that any released CAD files or other
released files which use Plaice's CAD files must share the preferred form of the source file for making modifications,
which is most often the derivative CAD file(s) in question. In adopting the license for CAD files, Plaice intends
to prevent the scenario of a designer privately holding on to a CAD file, and only releasing `.stl`s for public
consumption due to some ulterior motive (possibly, but not necessarily commercialization-related.) Plaice
_does not care_ if the designs are mass-printed and sold, but the project _does_ care about ensuring that
designers and consumers are on equal footing. If Plaice is part of somebody's path to becoming
a maker, that path should have as little resistance as possible.

CC-BY-SA is adopted for all other artifacts (including 3d models) as a pragmatic lowering to the case
where it doesn't make sense to reference an original source as in the OHL-S. The attribution and share-alike
components ensure that the ecosystem of derived files remains open to remixing, and that remixes all have
an unbroken chain of attribution. Both are crucial to the kind of ecosystem that Plaice intends to cultivate.

## How-To
There are multiple different ways to create new components for Plaice or to remix existing components,
each with their own tradeoffs: (1) Bolt-on Parts, (2) CAD derivatives, (3) STL Modifications.

### 1. Low Friction, Low Customizability: Bolt-On Parts

By far the easiest and most-preferred way to integrate with Plaice is to bolting printed parts on to
a Plaice [clipped or nubbed backing](/docs/components/Backings.md), as described in more detail on the [dedicated page](/docs/design/BoltOnComponents.md).
While this is low-friction for the designer, and is completely agnostic to choice
of technoogies, it only generally applies to components which only seek to integrate with the
[connector](/docs/design/ClipInterface.md)-and-[socket](/docs/design/Sockets.md) portion of Plaice.

### 2. Medium Friction, High Customizability: CAD Derivatives

The next-preferred way to integrate with Plaice is to leverage the FreeCAD files made available in this repository.
Parts in those files use a hybrid of referencing a spreadsheet (`sheet.FCStd`) for "Plaice global" values which define
the system, and copy-on-change linked objects with custom properties (see, e.g: [MangoJelly](https://www.patreon.com/mangojellysolutions)'s [video](https://www.youtube.com/watch?v=9mohplbz7Wg) about the topic) for values which
define the configurations of components. To use them, create a copy of the CAD directory from this repo, and
add new FreeCAD file(s) devoted to your design which reference the base Plaice system files, or modify the Plaice
system CAD files directly. Once you are finished with design, optionally export models of your component(s) at the different standard
clearance levels, and upload 'em somewhere together with any CAD files that you created, used or modified which depend on
Plaice components.

### 3. Medium-High Friction, High Customizability: STL Modifications

3D-printing has an extensive `.stl` remix culture, so it's important that Plaice supports the workflow.
However, in Plaice, the [clearances](/docs/design/Clearances.md) applied to connectors and slides are _meaningful_. There are good
structural reasons for individual users of the system to want to minimize those clearances, tuning
the system to their own printer. That means non-parametric 3d models are in a bit of a difficult
spot -- while they can be remixed, providing all standard clearance levels would require creating multiple
different copies of those models. That's somewhat of a pain! To partially settle this,
in the case of direct 3D model remixes, Plaice parts in the so-called "standard" clearance level are the preferred
source for edits.

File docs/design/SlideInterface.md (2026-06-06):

# Slide Interface
Slide Interface

Slide connections allow Plaice components to join in a way which leaves only one degree of freedom unconstrained. The _slide interface_
is the curve ("profile") projected on the plane normal to the degree of freedom which is sandwiched between an idealized
"perfect" protruding and intruding slide.

## Geometry

The Plaice slide interface profile draws on inspiration from jigsaw puzzle pieces and woodworking dovetails, but with its
shape optimized for strength. It's designed so that when connecting
two Plaice [plates](/docs/components/Plates.md) along a span supported at both ends, the slides will not break when a heavy weight is applied.

By itself, the need for strength does not completely define the interface profile. It becomes a bit more explainable when combined with the following other requirements:
- Leave at least `0.8 mm` (two perimeters with a `0.4 mm` nozzle) of material between a plate's [socket](/docs/design/Sockets.md)-chamfer and the slide profile. 
- Use simple geometric primitives (arcs and line segments)
- Ensure all arcs have greater than some minimum diameter (`0.8 mm`) to ensure smoothness in real prints.
- Prevent the two halves of a slide from seperating even under the largest clearance between slides employed by Plaice, without substantial force.

### Symmetries

Even with the listed geometric requirements, the shape is still fairly underspecified. To put the interface's shape into sharper focus,
we'll need to explicate what kinds of geometric symmetries are desirable.

There are two major symmetries which apply to the slide interface. Both are kinds of mirror symmetry, but
with different motivations: Ease of Assembly and Strength.

#### Ease of Assembly: Vertical Flip Symmetry

When putting two Plaice plates together with slides, assuming that a protruding and intruding slide are properly paired, the two plates
should fit together without needing to adjust their orientations. By ensuring that plates don't need to
be flipped to match orientations, the cognitive load (and hence, time) involved in putting together a Plaice assembly
is reduced. Namely, this means ensuring a vertical flip symmetry across a central horizontal axis.

#### Asymptotic Strength Under Plate Stacking
Slide Interface, Tessellated Slide Interface, Tessellated Slide Interface, Tessellated Slide Interface, Tessellated </div>

Stacked Plates

There are situations where '7mm' (HU) thick 3d-printed PLA plates just aren't going to cut it for a given loading.
In those situations, it's reasonable to want to stack plates on top of each other, and secure them to form a larger composite.
This option is readily available through the use of [thru-nubs](/docs/components/ThruNub.md) and [plugs](/docs/components/Plugs.md).

Now, consider what happens when a stack of plates with identical orientations is connected to another stack of plates
using slides -- schematically, the result looks something like the line-drawing above.

To minimize the maximal stress under an applied load, it is beneficial to spread the induced stresses
over the largest possible area. One natural way to do this for the situation of the stacked plates is to ensure
each stack should take a similar cumulative stress. There isn't a simple way to apply that
criterion verbatim, but we can do the next best thing: We can ensure that the _roles_ of each stack are the same in relation
to each other.

To do this, all we need to do is to ensure that between every two stacked protrusions, there's an intrusion formed, and
between every two stacked intrusions, there's a protrusion formed. This is another kind of mirror symmetry.

## FEM Optimization

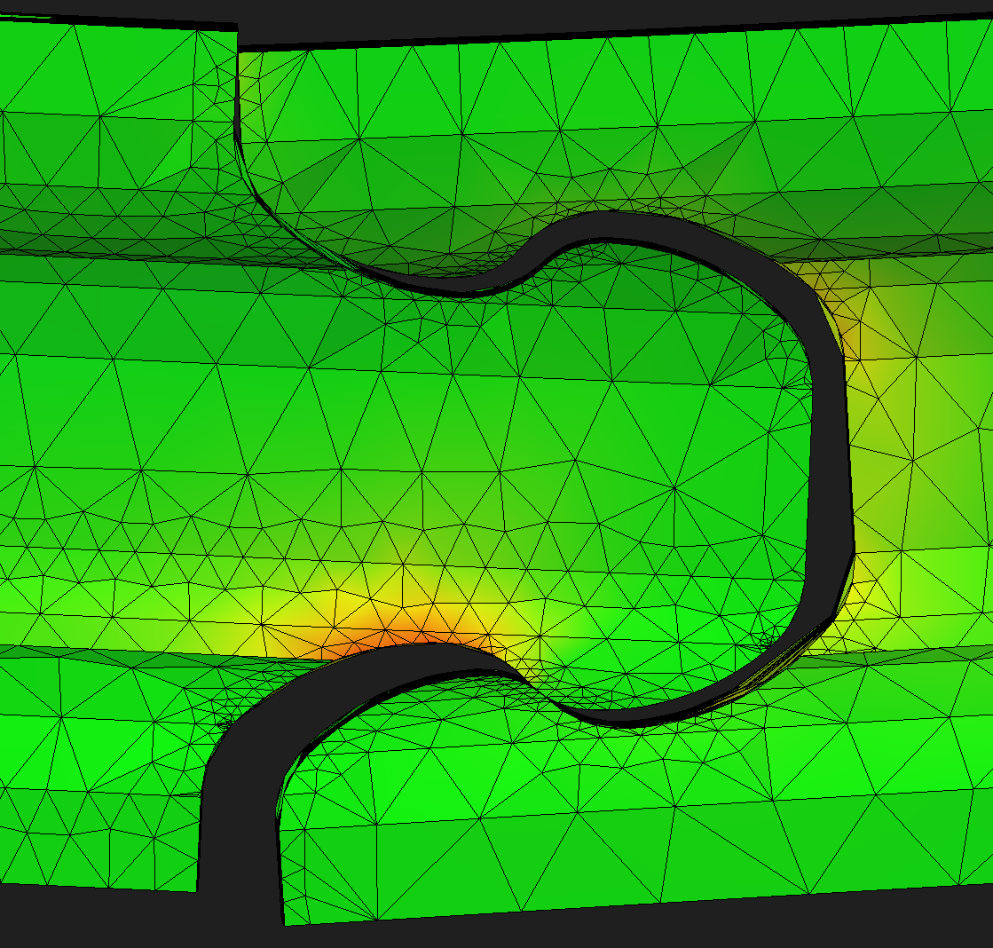
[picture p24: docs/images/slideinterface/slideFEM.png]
Slide FEM, Heatmap of Maximum Principal Stress


After the constraints mentioned in the previous section have been applied, the final shape of the Plaice slide interface is obtained
by performing hill-climbing on the maximal stress minimization objective. In particular, since the
objective assumes static loading, and PLA is dramatically stronger under compression than under tension, we can apply the Mohr-Coulomb yield
criterion and use the (max of the) maximum principal stress as a proxy for how close to yielding our parts are. 

## Clearances and Manufacturing Notes

For the slides to fit together, there needs to be some amount of clearance between protruding and intruding slides. Additionally, process-specific (3d printing)
biases need to be corrected for. See [the dedicated design page on clearances](/docs/design/Clearances.md).

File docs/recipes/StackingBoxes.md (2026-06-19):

# Recipe: Stacking Boxes

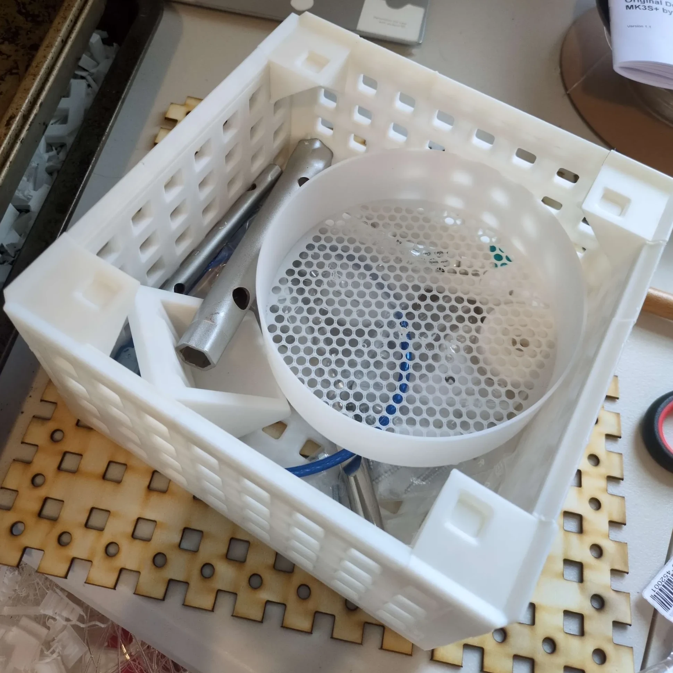
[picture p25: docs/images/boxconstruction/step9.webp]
Step 9 Visual
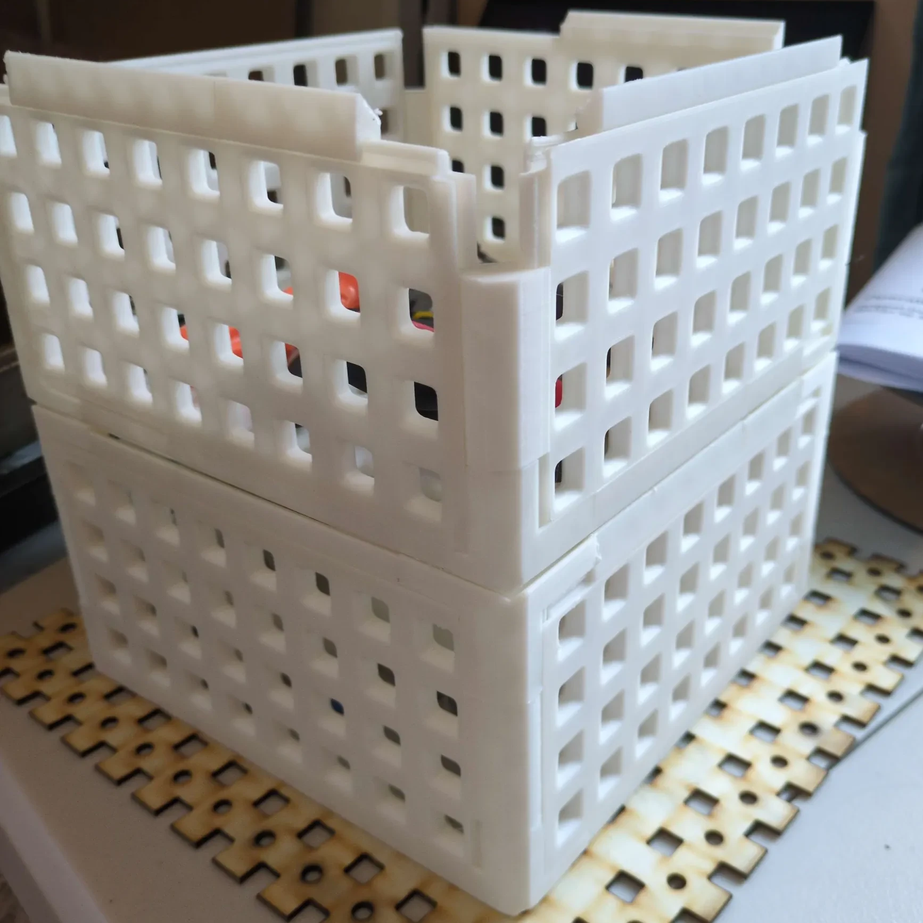
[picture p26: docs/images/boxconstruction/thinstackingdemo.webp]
Thin Corner Stacking Cap Boxes Demonstration
 Step 8 Visual 

In this recipe, we'll make stacking boxes which are [`8 CU x 8 CU x 4 CU`](/docs/design/Units.md), suitable for
e.g: organization of miscellaneous project materials. The steps in this recipe can be followed to construct
stacking boxes in any other sizing by adjusting the dimensions of the components involved. 

## Ingredients (per box)
- 1 `8 CU x 8 CU` [Plate](/docs/components/Plates.md)\*
- 4 `4 CU x 8 CU` Plates\*
- 8 `2 CU` [Corners](/docs/components/Corners.md)\*
- 4 `4 CU` Corners\*
- 4 [Corner Caps](/docs/components/CornerCaps.md)
- 4 `6 mm` [M2 Bolts](/docs/design/M2Bolts.md)
- 4 M2 Nuts
- 2 `4 CU` Protruding [Stacking Lips](/docs/components/StackingLips.md)\*
- 2 `4 CU` Intruding Stacking Lips\*
- 2 `2 CU` Protruding Stacking Lips\*
- 2 `2 CU` Intruding Stacking Lips\*
- 4 [Thin or Thick Corner Stacking Caps](/docs/components/CornerStackingCaps.md)
- (If using thick corner stacking caps): 4 [Stacking Pegs](/docs/components/StackingPeg.md)
- (If using thick corner stacking caps): 4 [Clipped Plugs](/docs/components/Plugs.md)

\*: Any same-size composite of smaller components will also work.

## Step 1
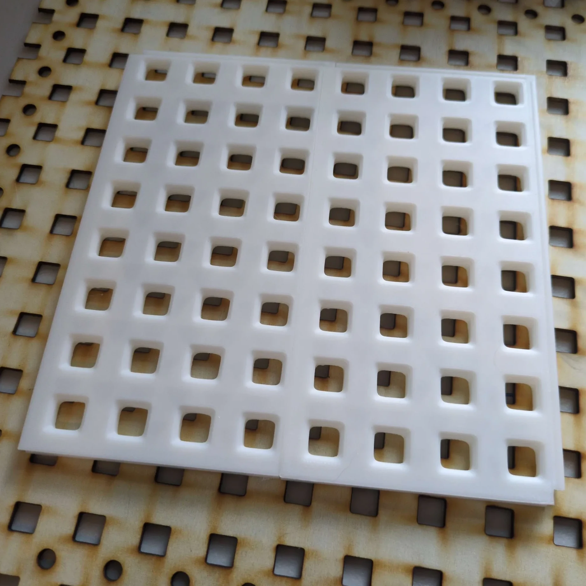
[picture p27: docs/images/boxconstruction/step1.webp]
Step 1 Visual


Start by placing down an `8 CU x 8 CU` plate to serve as the base of the box.

## Step 2
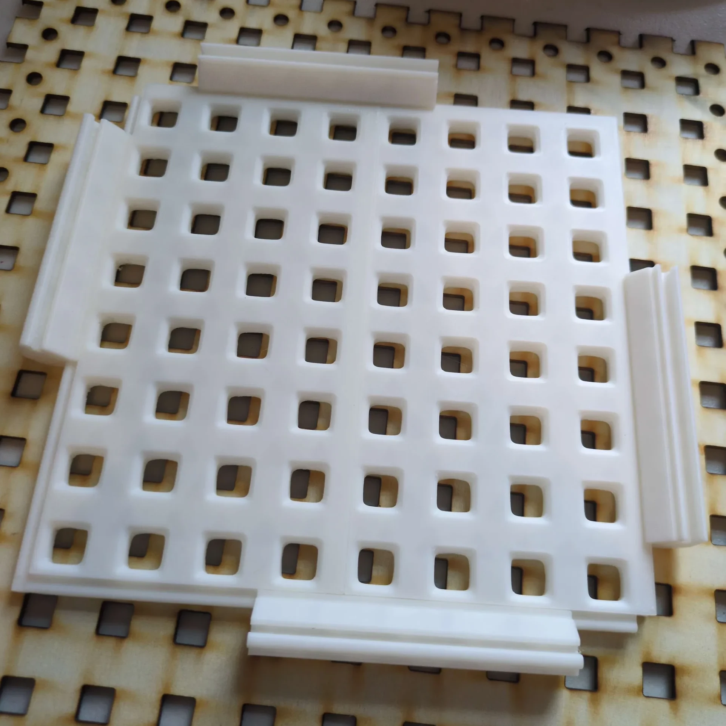
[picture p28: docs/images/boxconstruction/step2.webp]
Step 2 Visual


Slide four `4 CU` corners onto the plate as shown. If you find the corners difficult to slide on,
you may want to change the [clearance](/docs/design/Clearances.md) level to something looser. However, the tighter
components may still be usable, but you may need assistance from a rubber mallet
and/or pliers.

## Step 3
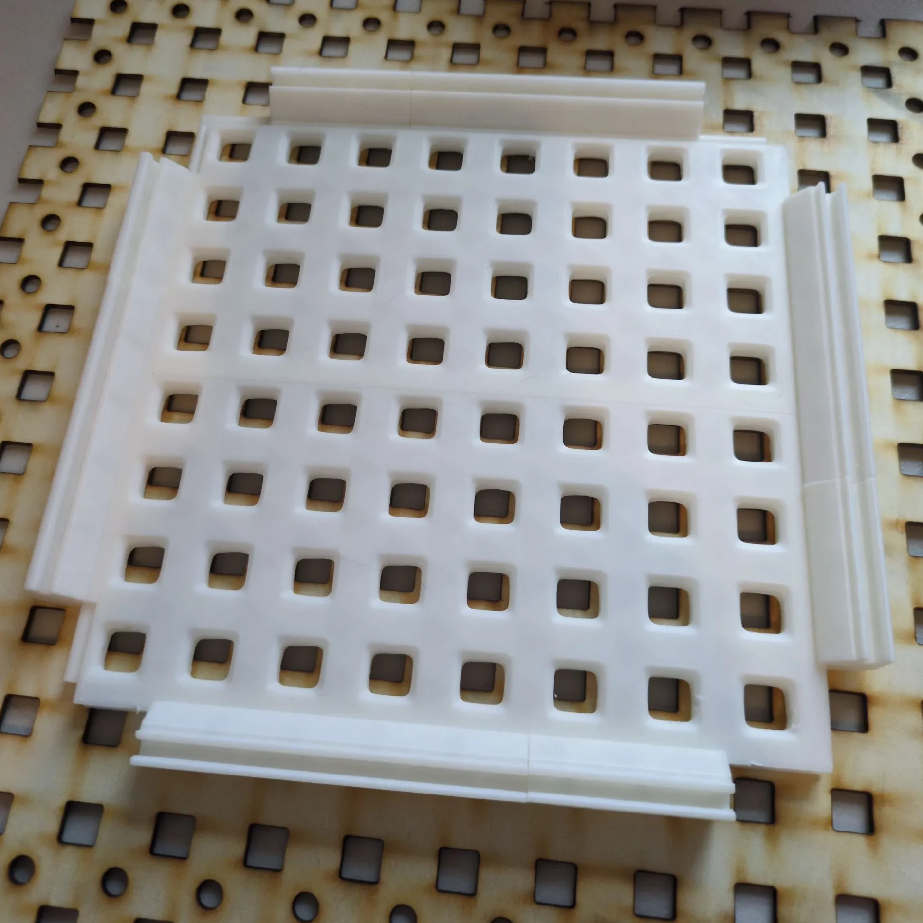
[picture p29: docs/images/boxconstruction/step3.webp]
Step 3 Visual


Slide four `2 CU` corners onto the plate. Try to align the resulting `6 CU` composite
corners so that each of their ends are `1 CU` inset from the outer boundary of the base plate
to approximate their final position, but this isn't strictly necessary.

## Step 4
Step 4 Visual

Slide four `4 CU x 8 CU` plates onto the corners added in the previous step. Try to ensure that
the directionality of the protrusions is counter-clockwise, unlike in the picture for this step,
which shows them clockwise. If you do have them oriented as shown in the picture, you will need
to mirror the corner stacking caps listed in the ingredients in your slicer prior
to printing.

## Step 5
Step 5a Visual

Take the outer part for a corner cap and insert a nut into its captive nut channel,
then place it on the outside of the box-under-construction at an interface between
three corner slides.

Step 5b Visual

With the outer part of the corner cap in place, take the inner part and place it on
the inside of the box, opposite to the previously-placed outer part. Secure it in place
with a `6 mm` M2 bolt.

Step 5c Visual

Repeat this step for all four bottom corners of the box-under-construction.

Step 5d Visual

## Step 6
Step 6 Visual

Flip the box back over and slide four `2 CU` corners on top of the corner caps, leaving
`1 CU` gaps at the top. If you don't care about stacking, you could stop the recipe here
(but maybe add `1 CU` corners to close the aforementioned gaps) and have perfectly
functional boxes. Otherwise, continue.

## Step 7
Step 7 Visual

Slide on the intruding and protruding stacking lips as shown, leaving `1 CU` gaps on each side
of each plate.

## Step 8 (Thin Corner Stacking Caps)
Step 8 Visual

If you opt for thin corner stacking caps over thick ones, finish off the boxes by sliding
those on. If you had picked clockwise protrusions in step 4, these will need to be mirrored.

**Done**

Thin Corner Stacking Cap Boxes Demonstration

The above picture shows the finished box on the bottom with a partially-constructed identical box stacked on top.
This configuration is perfectly servicable, but potentially prone to having the the top box accidentally bumped
out of alignment in high-traffic areas. Additionally, larger, heavier boxes with the same construction may have too much
accumulated displacement in their walls, which could compromise the stacking mechanism employed here.
For a more robust alternative, continue.

## Step 9 (Thick Corner Stacking Caps)
Step 9 Visual

If you opt for thick corner stacking caps over thin ones, finish off the boxes by sliding those on.
If you had picked clockwise protrusions in step 4, these will need to be mirrored.

## Step 10
Step 10 Visual

For each other box that you want to be able to stack on your box, snap together four stacking pegs
and four clipped plugs at the corners of the base plate for the box, with the stacking pegs facing
downwards.

**Done**

Thick Corner Stacking Cap Boxes Demonstration

If you stack the boxes, you will notice that the stacking pegs slide into the sockets of the thick corner stacking caps,
preventing lateral movement without physically lifting the box on top.

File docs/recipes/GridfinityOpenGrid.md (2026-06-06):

# Recipe: Gridfinity + OpenGrid Desktop Organizer
Finished Result

In this recipe, we'll construct a two-sided desktop organizer for tools and hardware consisting of a
horizontal base of Gridfinity baseplates and a vertical dividing wall with OpenGrid baseplates
on either side of it. In the process, we'll demonstrate how to use bolt-on components (TODO: link)
together with clipped and nubbed backings (TODO: link) to extend Plaice with external components.

## Ingredients

- 4 `2 x 2` Gridfinity Baseplate Bolt-ons (TODO: link) \*
- 8 OpenGrid Baseplate Bolt-ons (TODO: link)
- 2 `4 CU x 8 CU` [Plates](/docs/components/Plates.md) \*
- 1 `8 CU x 8 CU` Plate \*
- 1 `2 CU x 8 CU` Plate \*
- 1 `8 CU` [Protruding Tee](/docs/components/CrossesAndTees.md) \*
- 1 `8 CU x 8 CU` [Nubbed Cover](/docs/components/Covers.md) \*
- 1 `1 CU x 8 CU` Nubbed Cover \*
- 8 `4 CU x 4 CU` Clipped Backings (TODO: Link) \*
- 4 `4 CU x 4 CU` Nubbed Backings \*
- 32 M2 Nuts
- 16 `16 mm` M2 Bolts
- 16 `8 mm` M2 Bolts

\*: Any same-size composite of smaller components will also work.

## Step 1
Step 1

Place the two `4 CU x 8 CU` plates next to each other in the same orientation.

## Step 2
Step 2

Slide the protruding slide between the two plates.

## Step 3
Step 3

Slide the `8 CU x 8 CU` plate onto the protruding slide.

## Step 4
Step 4a Step 4b

Flip the entire assembly upside-down and insert the `8 CU x 8 CU` nubbed cover into the
exposed [sockets](/docs/design/Sockets.md). If using a composite of covers, try to
ensure that they span the middle of the assembly rigidly.

## Step 5
Step 5

Insert the `1 CU x 8 CU` nubbed cover into the remaining sockets.

## Step 6
Step 6

Flip the assembly back over and snap four `4 CU x 4 CU` clipped backings onto the bottom
plate (which secures the nubbed covers in place.)

## Step 7
Step 7

Position a Gridfinity baseplate bolt-on over one of the clipped backings, aligning the
holes as best you can.

## Step 8
Step 8

Insert four M2 nuts into the four cornermost captive nut recesses of the Gridfinity
baseplate bolt-on.

## Step 9
Step 9

Hold the Gridfinity baseplate bolt-on in place, and flip the assembly on its side.
At each hole with a nut inserted in step 8, insert and gently tighten an `8 mm` M2 bolt.

## Step 10
Step 10

Repeat the previous steps from step 7 for all Gridfinity baseplates.

## Step 11
Step 11a Step 11b

Take one `4 CU x 4 CU` clipped backing and one nubbed backing and snap them together on
either side of the vertically-oriented plate, leaving at least `2 CU` of the plate at the
bottom for clearance between Gridfinity and OpenGrid components.

## Step 12
Step 12

Take an OpenGrid baseplate bolt-on and hold it in alignment with the holes of the backings
from the previous step (either side will work).

## Step 13
Step 13a Step 13b

With your free hand, insert four `16 mm` M2 bolts into the corner holes of the OpenGrid
baseplate bolt-on. So long as you keep the assembly upright, you will no longer need
to hold onto the OpenGrid baseplate like you did in step 12.

Turn the assembly around so that you can see the bolts protruding through.

## Step 14
Step 14

Snap four M2 nuts into another OpenGrid baseplate bolt-on and gently slide it on to the exposed
ends of the bolts from the previous step. Hold the two baseplates on either side together with
one of your hands.

## Step 15
Step 15a Step 15b

Gently tighten the four bolts you inserted in step 13. Once completed, you should be able
to free both of your hands.

## Step 16
Step 16

Repeat the previous steps from step 11 for another pair of OpenGrid baseplates.

## Step 17
Step 17

Slide the `2 CU x 8 CU` plate on top of the vertically-oriented `8 CU x 8 CU` plate.

## Step 18
Step 18

Repeat steps 11-15 to secure the remaining OpenGrid baseplates.

Finished Result

## ...Finish!

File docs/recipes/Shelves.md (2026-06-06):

# Recipe: Shelves
Step 10 Visual Step 18 Visual 2 Step 22 Visual 

In this recipe, we'll make shelves which are [`18 HU`](/docs/design/Units.md) tall with a `12 CU x 8 CU` surface,
suitable for small desk or kitchen organization tasks (e.g: extra storage for mugs in cabinets). The steps in this
recipe will also cover how to reinforce shelves using M2 nuts and bolts together with [covers](/docs/components/Covers.md),
and how to iterate the construction steps of this recipe to build multi-tier shelf assemblies. 

## Ingredients (Per Tier)
- 1 `8 CU x 8 CU` [Plate](/docs/components/Plates.md)\*
- 1 `4 CU x 8 CU` Plate\*
- 4 `18 HU` tall, `2 CU x 2 CU` Tapered [Beams](/docs/components/Beams.md)\*
### [Plugged](/docs/components/Plugs.md) Variant
- 16 Clipped Plugs
- Optional: 16 M2 Nuts + 16 M2 6mm Bolts
### [Covered](/docs/components/Covers.md) Variant
- 1 `8 CU x 8 CU` Clipped Cover\*
- 1 `4 CU x 8 CU` Clipped Cover\*
- 1 `8 CU x 8 CU` Nubbed Cover\*
- 2 `2 CU x 4 CU` Nubbed Covers\*
- Optional: 28 M2 Nuts + 16 M2 10mm Bolts + 12 M2 6mm Bolts
### Stacked Variant
- 4 [Thru-Nubs](/docs/components/ThruNubs.md) for every tier above the first
- Optional: 1 M2 16mm bolt for every thru-nub. 

\*: Any same-size composite of smaller components will also work.

## Step 1
Step 1 Visual

Start by placing down an `8 CU x 8 CU` plate to serve as part of the surface of the shelf.

## Step 2
Step 2 Visual

Slide the `4 CU x 8 CU` plate onto the `8 CU x 8 CU` plate to form a composite `12 CU x 8 CU` plate.

## Step 3
Step 3 Visual

Place one of the `18 HU` beams into the [sockets](/docs/design/Sockets.md) at a corner of
the `12 CU x 8 CU` composite plate, oriented with the body of the beam at the corner socket,
and with the tapers facing toward the center of the plate. 

## Step 4a (Plugged, No Bolts)
Step 4a Visual

Holding the beam in place with one hand, flip the entire assembly over, and using your other hand,
snap four clipped plugs onto the nubs from the beam, through the sockets. 

## Step 4b (Plugged, No Bolts)
Step 4b Visual

Repeat the above two steps for the other three beams to finish the shelf. This shelf
as it is suffices to hold a ~`1.5 kg` machinists' hammer (pictured), but its overall
weight capacity is limited by the fact that the legs are attached only by the
clip-and-nub connectors, which will detach once enough force is applied.

To resolve this issue, we can add M2 hardware to reinforce the connection
between the plugs and the legs of the shelf, which we demonstrate in the following steps.

## Step 5 (Plugged, Bolts)
Step 5 Visual

For each of the clipped plugs mentioned in step 4(a+b), insert a M2 nut into the dedicated
captive nut channel. Make sure that the nuts are pushed as far back as they go with light pressure.

If you had previously done step 4, you can remove the plugs from their sockets by either pulling
off the legs of the shelf with moderate pressure, or by carefully prying the plugs out with a small flathead screwdriver.

## Step 6 (Plugged, Bolts)
Step 6 Visual

Snap the clipped plugs onto the nubs of the beam, just like in step 4.

## Step 7 (Plugged, Bolts)
Step 7 Visual

Flip the assembly over. For all but the corner sockets, take 6mm M2 bolts and screw them in to the dedicated
holes on the beam so that they engage with the captive nuts in the clipped plugs on the other side of the socket.
Tighten until you feel moderate resistance, but do not overtighten. 

## Step 8 (Plugged, Bolts)
Step 8 Visual

Insert 6mm M2 bolts into the holes for the corner sockets using the cut-outs in the beams. For this step, it helps
somewhat to have a magnetic screwdriver or to angle the assembly to assist with bolt seating. Then, take a standard
1.5mm small hex key and tighten the bolts as shown. 

## Step 9 (Plugged, Bolts)
Step 9 Visual

Repeat the previous three steps for each leg of the shelf.

## Step 10 (Plugged, Bolts)
Step 10 Visual

Finish (Plugged + Bolts configuration)

With the bolts in place, the legs are no longer at risk of falling off when the weight
on top of the shelf is increased, but if you look closely in the picture, you might
notice that the surface of the shelf sags somewhat about the seam where the plates
making up the surface are joined via slides. To resolve this issue, and make it
so that the entire surface of the shelf behaves homogenously, follow along with
the next steps, which will show how to affix covers to the assembly.

## Step 11 (Covered, Bolts)
Step 11 Visual

Revert all the way back to step 2. Prepare one of the `4 x 8 CU` clipped covers by inserting
M2 nuts into the captive nut channels. You do not need to insert nuts into _every_ captive
nut channel, simply enough to later engage with associated bolts for the beams, one for every
corner of the clipped cover, and one for every position which will mate with the corner
bolts of a nubbed cover on the bottom of the plate. Don't worry about getting
this perfect the first time, but ensure that you stay on steps 11 and 12 before proceeding
to minimize wasted effort. 

## Step 12 (Covered, Bolts)
Step 12 Visual 1 Step 12 Visual 2

Repeat step 11 for all clipped covers demanded for this recipe. While doing this, it helps
to flip the assembly upside down and test-position nubbed covers over the assembly to
determine where the captive M2 nuts should go. Sample pattern shown in picture.

## Step 13 (Covered, Bolts)
Step 13 Visual

Position the nubbed covers as shown, and snap them into place.

## Step 14 (Covered, Bolts)
Step 14 Visual

Take the 10mm M2 bolts and screw them into every corner of every clipped and nubbed cover.
If you lose track of where to place them, looking carefully at each hole can help, since
at certain angles the internal threads of the nuts placed in earlier steps may still be
visible. 

## Step 15 (Covered, Bolts)
Step 15 Visual

Snap in a beam at one of the corners, and attach the three inner 10mm M2 bolts.

## Step 16 (Covered, Bolts)
Step 16 Visual

Insert one more 10mm M2 bolt into the internal channel of the beam, and lightly
tighten using a hex key.

## Step 17 (Covered, Bolts)
Step 17 Visual

Repeat the previous two steps for the remaining three beams.

## Step 18 (Covered, Bolts)
Step 18 Visual 1 Step 18 Visual 2

Papillon for scale.

Finish (Covered + Bolts Configuration)

Now our single-tier shelf is looking pretty sturdy! However, a single-tier shelf is just...
a table. What if we want multiple shelf tiers? Well, doing so is fairly simple -- read on!

## Step 19 (Stacking)
Step 19 Visual

To start, assemble multiple shelving tiers by following one or more of the journeys above. 
In our case, we have a plugged shelf which we'll place on the bottom, and a covered
shelf which we'll be placing as the top tier. It's possible to have either configuration,
but in our case, we would need to print different-size covers if we wanted the covered
shelf on the bottom.

Remove the plugs at the corners of the bottom-tier shelf. (If doing this with a covered
shelf instead, you will need to change the pattern of clipped covers to accommodate
`1 CU x 1 CU` gaps at each of the corners.)

## Step 20 (Stacking)
Step 20 Visual

Snap a thru-nub into one of the corners of the bottom tier's surface.

## Step 21 (Stacking)
Step 21 Visual

Slide an M2 bolt into the nut channel of the corresponding beam of the top tier.
Repeat this step and the previous one for all four corners.

## Step 22 (Stacking)
Step 22 Visual

Snap the four beams of the top tier onto the thru-nubs of the bottom tier, and secure
with four 16mm M2 bolts. Iterate the stacking steps if you want to add more tiers.

## ...Finish!

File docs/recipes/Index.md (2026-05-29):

# Recipes Index

## [Clearance Calibration](/docs/recipes/ClearanceCalibration.md)
Two plates slid together

## [Gridfinity + OpenGrid Desk Organizer](/docs/recipes/GridfinityOpenGrid.md)
Gridfinity+OpenGrid Organizer

## [Shelves](/docs/recipes/Shelves.md)
Step 10 Visual Step 18 Visual 2 Step 22 Visual 

## [Spice Organizer](/docs/recipes/SpiceOrganizer.md)
Finished Result

## [Stacking Boxes](/docs/recipes/StackingBoxes.md)
Step 9 Visual Step 8 Visual Thin Corner Stacking Cap Boxes Demonstration

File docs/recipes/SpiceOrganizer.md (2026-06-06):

# Recipe: Spice Organizer
Finished Result

In this recipe, we'll make a modular spice organizer suited for small-to-mid-size spice containers.
In the process, we'll demonstrate how to orient slides in grid-structured assemblies
involving [crosses and tees](/docs/components/CrossesAndTees.md).

## Ingredients (`W` x `H` Array)

- `2 * W * H + W + H` Copies of `2 CU x 4 CU` [Plates](/docs/components/Plates.md)

- `(W - 1) * (H - 1)` slide-crosses

- `W + H - 2` protruding slide-tees

- `W + H - 2` intruding slide-tees

- 4 [Corners](/docs/components/Corners.md)

## Step 1
Step 1 Visual

Lay down all the plates which make up the base of the organizer as shown. Ensure that all
protruding slides are pointing in the same direction.

## Step 2
Step 2 Visual

In between each adjacent pair of places, slide on some of the tees. Make sure to
alternate between intruding and protruding tees, this will be important later.
Don't worry about getting the alignment perfect, this can always be corrected later.

## Step 3
Step 3 Visual

Slide the corners onto the base.

## Step 4
Step 4 Visual

For every upward-facing slide (protruding or intruding), slide a plate on it.

## Step 5
Step 5 Visual

For all upward-facing slides which are not on the ends, slide a cross onto it.
Ensure that the orientation of the crosses is such that for every partially-completed
top "cell" (which would accommodate a spice container), the orientation of protruding
slides is consistent (clockwise or counterclockwise) about the loop around the edges of the cell
(see picture). 

## Step 6
Step 6 Visual

Slide protruding and intruding tees onto the edges, making sure to follow the orientation
constraint mentioned in the previous step.

## Step 7
Step 7 Visual

Between every adjacent pair of crosses, tees, or a pairing of a cross and a tee, slide
a plate between them. Like in step 1, their protrusions should all face in the same
direction, but one which is the opposite of the previous tier.

## Step 8
Step 8 Visual

Iterate the previous steps from step 4, with the top tier instead substituting corners
in place of tees and tees in place of crosses.

## ...Finish!

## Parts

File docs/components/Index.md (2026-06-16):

# Components Index

## [Backings](/docs/components/Backings.md)
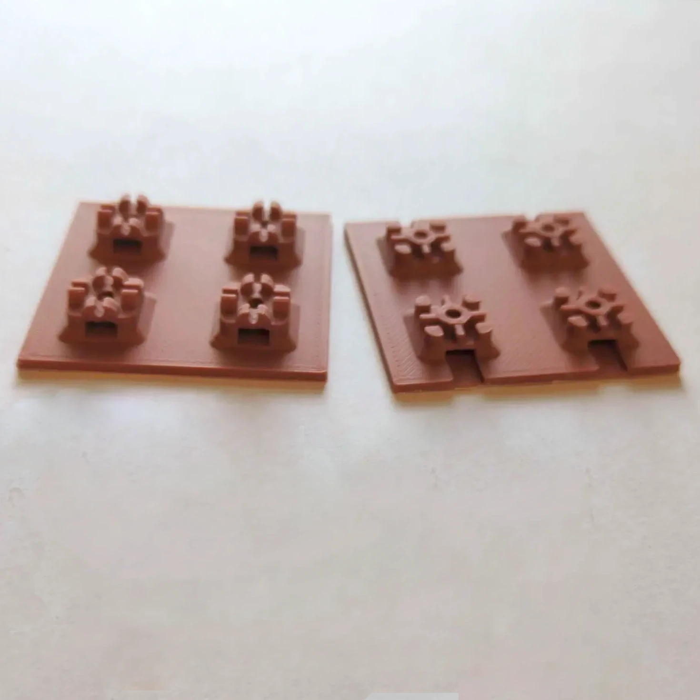
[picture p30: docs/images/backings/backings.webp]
Clipped and Nubbed Backings


## [Beams](/docs/components/Beams.md)
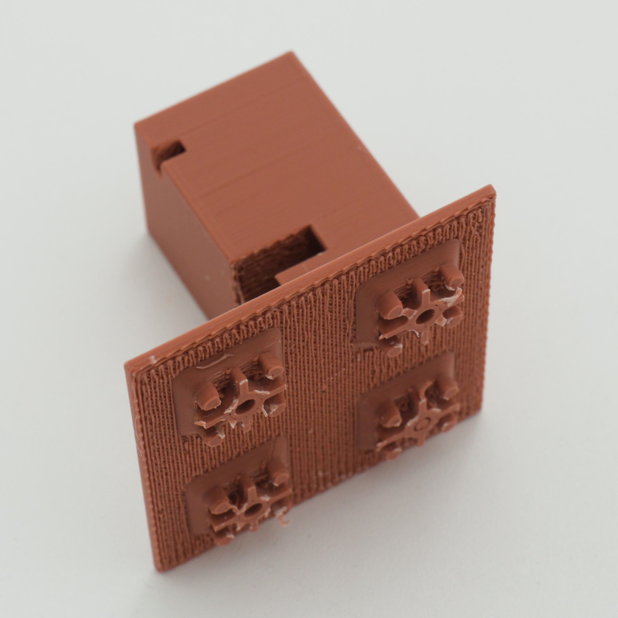
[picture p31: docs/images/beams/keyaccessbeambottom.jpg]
A Key-Access Beam, Bottom View
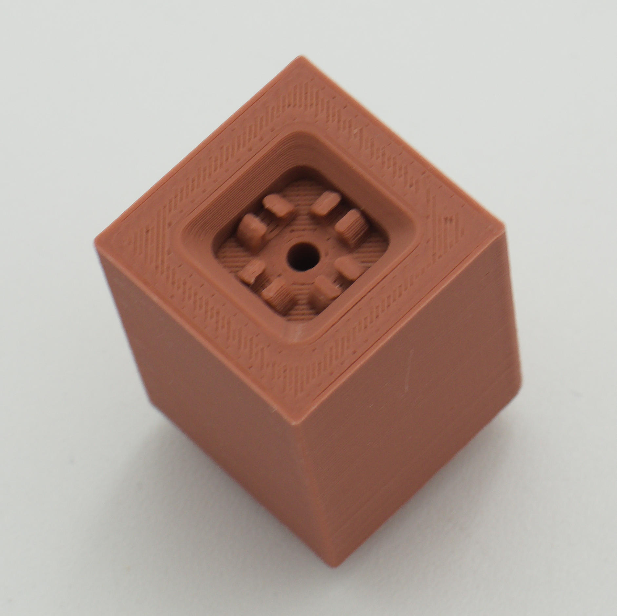
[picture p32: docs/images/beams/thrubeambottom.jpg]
A Thru Beam, Bottom View
 

## [Corner Caps](/docs/components/CornerCaps.md)
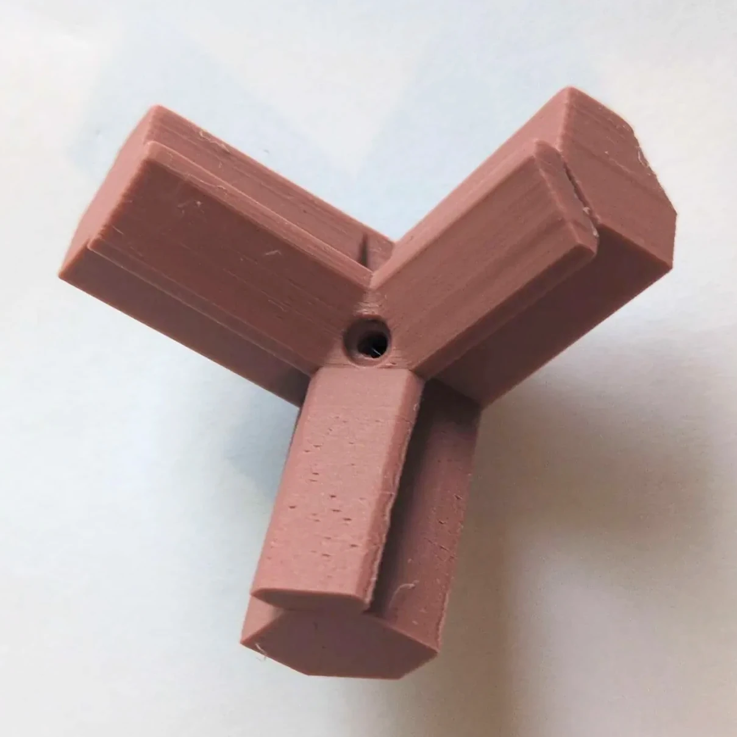
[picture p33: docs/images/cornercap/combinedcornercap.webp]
A Corner Cap, Parts Combined
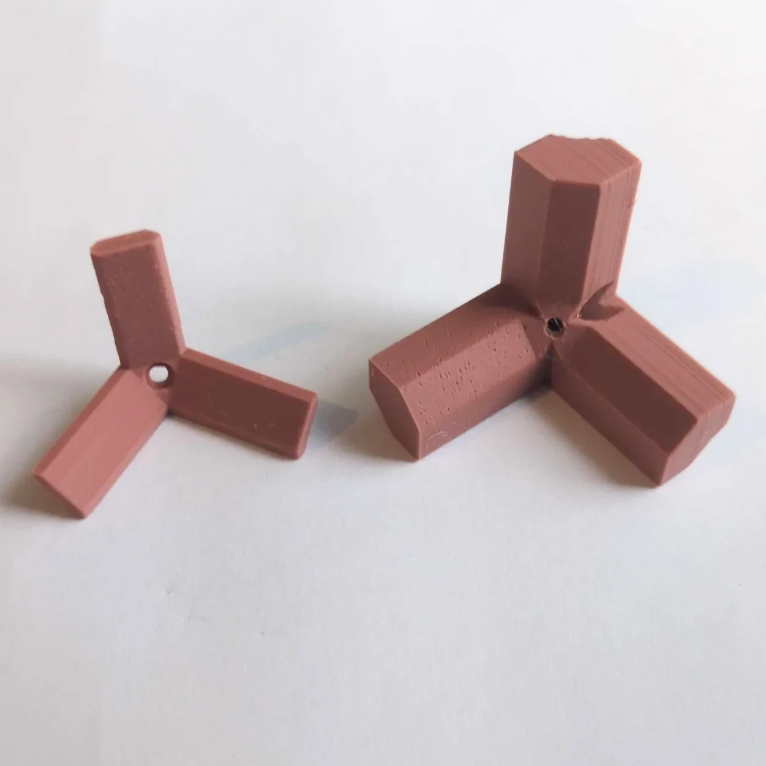
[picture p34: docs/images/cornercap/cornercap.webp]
A Corner Cap
 

## [Corner Stacking Caps](/docs/components/CornerStackingCaps.md)
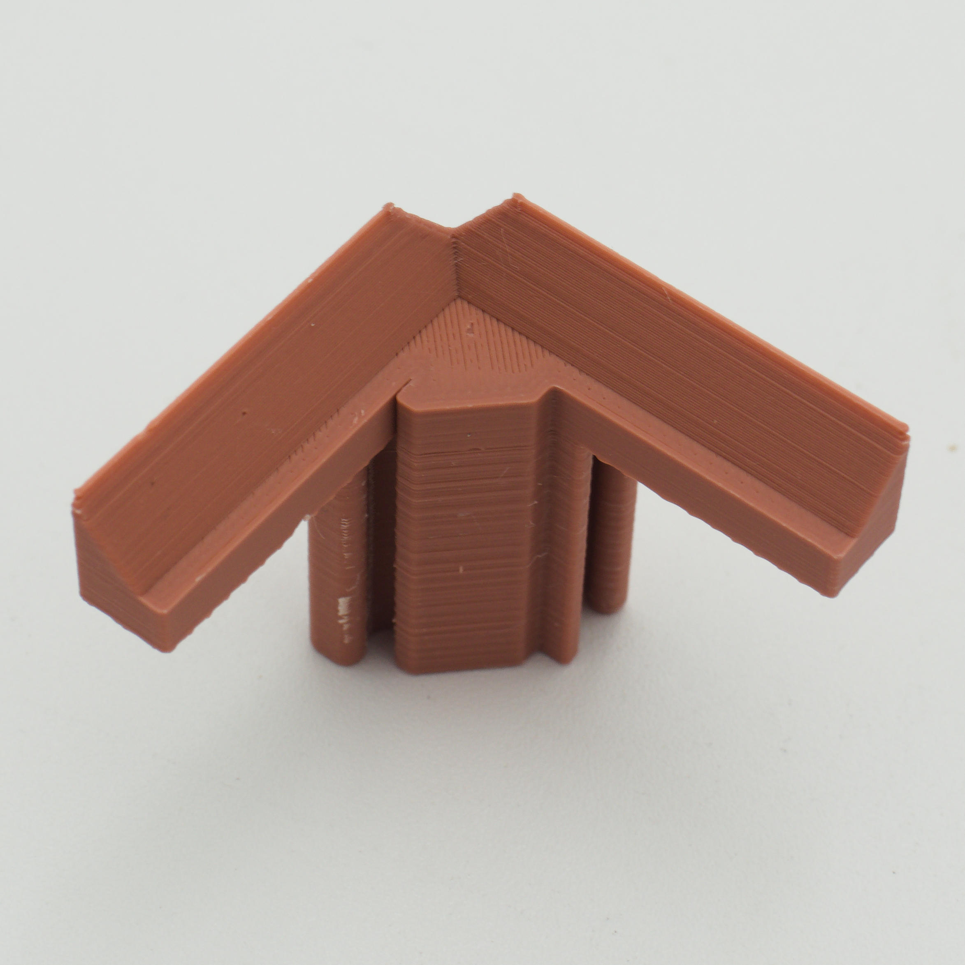
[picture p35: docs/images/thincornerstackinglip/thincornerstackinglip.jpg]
A Thin Corner Stacking Cap
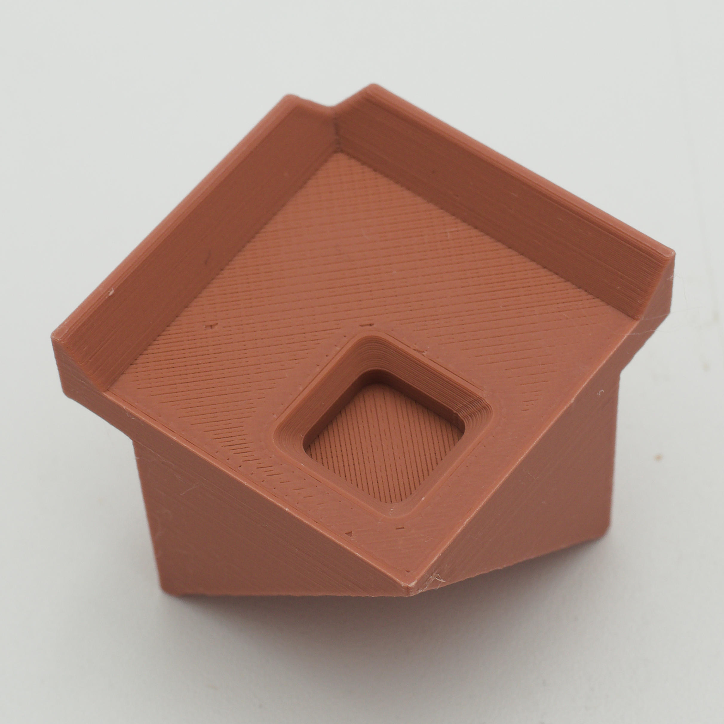
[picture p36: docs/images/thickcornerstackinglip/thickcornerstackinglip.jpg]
A Thick Corner Stacking Cap
 

## [Corners](/docs/components/Corners.md)
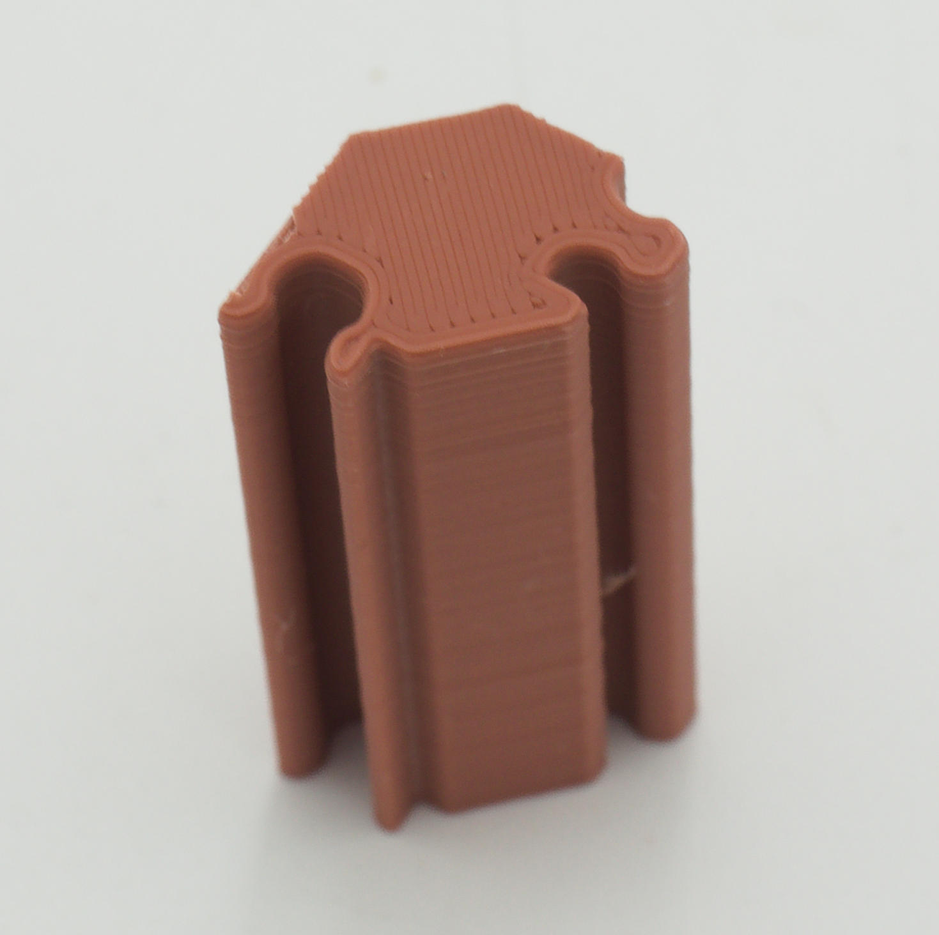
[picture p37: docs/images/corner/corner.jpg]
A Corner


## [Covers](/docs/components/Covers.md)
A Clipped Cover, Top View A Nubbed Cover, Bottom View 

## [Crosses and Tees](/docs/components/CrossesAndTees.md)
Crosses, Glide and Slide Tees, Top row Slides, Bottom Glides, Protruding and Intruding

## [Gridfinity Integration](/docs/components/GridfinityIntegration.md)
A Gridfinity Baseplate Bolt-On A Gridfinity Bin Base Bolt-On

## [Hinges](/docs/components/Hinges.md)
A Hinge

## [OpenGrid Integration](/docs/components/OpenGridIntegration.md)
An OpenGrid baseplate bolt-on An OpenGrid snap bolt-on

## [Plates](/docs/components/Plates.md)
A 2x2 Plaice Plate

## [Plugs](/docs/components/Plugs.md)
Plugs, Clipped and Nubbed, Bottom Views Plugs, Clipped and Nubbed, Top Views

## [Slide and Glide Bolt-Ons](/docs/components/SlideAndGlideBoltOns.md)
A collection of slide and glide bolt-ons

## [Stacking Lips](/docs/components/StackingLips.md)
Stacking Lips, Intruding and Protruding

## [Stacking Pegs](/docs/components/StackingPeg.md)
A Stacking Peg, Bottom View A Stacking Peg, Side View 

## [Thru Nubs](/docs/components/ThruNub.md)
A Thru-nub, Side View A Thru-nub, Top View

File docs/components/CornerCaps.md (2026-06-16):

# Corner Caps

A Corner Cap A Corner Cap, Back View 
A Corner Cap, Both Halves 

Plaice corner caps are used whenever three Plaice [corners](/docs/components/Corners.md) meet with three [plates](/docs/components/Plates.md) spanning between them, and they
"cap off" the remaining space at the inerface between the slides. They are composed of an inner part and an outer part which are meant to be joined together with
a `6 mm` [M2 bolt and nut pair](/docs/design/M2Bolts.md) to straddle the inner and outer sides of a three-corner interface.

The inner part is the smaller of the two, with a pocket designed for insertion of M2 bolts. Those bolts, in turn, are meant to connect through to a captive nut
inserted into the outer part. See [the recipe for stacking boxes](/docs/recipes/StackingBoxes.md) for more details.

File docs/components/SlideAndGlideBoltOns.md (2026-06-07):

# Slide (and Glide) Bolt-Ons
A collection of slide and glide bolt-ons

These components allow attaching [slide or glide](/docs/design/SlideInterface.md) connectors of some length `L` in 
[cell units](/docs/design/Units.md) via the [bolt-on interface](/docs/design/BoltOnComponents.md) to [backings](/docs/components/Backings.md) of size `1 CU x L CU`,
effectively allowing slides (or glides) to be mounted arbitrarily to the surface of a Plaice [plate](/docs/components/Plates.md). 

In the picture above, the top row shows glide bolt-ons, and the bottom row shows slide bolt-ons, with protruding slides/glides
to the left and intruding ones to the right.

The positioning of the slide interface is set to match the positioning
of plates which would otherwise be obtained via [crosses and tees](/docs/components/CrossesAndTees.md). They are largely useful
for adding impromptu "dividers" to box-like Plaice constructions without needing to deconstruct and reconstruct
the larger container, as would be required for crosses and tees.

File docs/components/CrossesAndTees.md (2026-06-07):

# Crosses and Tees

Crosses, Glide and Slide Tees, Top row Slides, Bottom Glides, Protruding and Intruding

It's common in Plaice for two or more [plates](/docs/components/Plates.md) to meet at right angles to each other, with some kind of connector between them. In the case
where there are only two plates, [corners](/docs/components/Corners.md) are used, but in situations where more plates meet, crosses and tees are needed instead.

## Crosses
Crosses, Glide and Slide 

When four plates meet, a cross connector may be used to hold them together with [slide](/docs/design/SlideInterface.md) (or glide) connections. 

Glide connections are denoted with two parallel lines engraved onto the top and bottom faces, with the connectors "sandwiched"
between them being the glide connections, and the other connectors assumed to be slides. 

The spacing of slide connectors on a cross are set up to ensure that along each straight, exactly one [cell unit](/docs/design/Units.md) (`1 CU`) is consumed,
which ensures that Plaice plates with crosses maintain alignment with contiguous Plaice plates. 

The chamfers between the four prongs of a cross are interrupted by `.25 HU` straights to allow for flush mounting of Plaice [covers](/docs/components/Covers.md).

The intruding and protruding connectors of crosses are set up so as to not reverse the directionality of slide connectors on Plaice plates
connected along the straights of the cross, which enables easier reasoning about plate orientations. 

## Tees
Tees, Top row Slides, Bottom Glides, Protruding and Intruding

Tees are for when three Plaice plates meet. They are basically crosses with one of the slide connectors removed, with the removed-connector
side given several stub Plaice [sockets](/docs/design/Sockets.md) along the flat. This is done to maintain the continuity of the socket grid across plates connected
along the flat. 

Tees are named after whether their right-angle connection is protruding or intruding, and the clearance level (slide or glide). 
Just like with crosses, "glide" tees are denoted by two parallel lines engraved onto the top and bottom faces. 

### Printability modifications
A Protruding Slide Tee, just after printing

All tees have a printability modification which adds three thick brim segments to their outer straights to help prevent the tee from toppling while printing.

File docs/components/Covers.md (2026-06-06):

# Covers
A Clipped Cover, Top View A Nubbed Cover, Bottom View 

Clipped and nubbed covers are Plaice components which go one step further from [plugs](/docs/components/Plugs.md), and add a thin `1.7 mm` (approximately [`.25 HU`](/docs/design/Units.md)) slab of material over the top of a bunch of plugs.
They may be used to conceal or prettify Plaice [plates](/docs/components/Plates.md), to create colored patterns, or even as structural reinforcement to "correct" deflection between
two [slide-connected](/docs/design/SlideInterface.md) plates. (For an example of deflection correction, see the [recipe for shelves](/docs/recipes/Shelves.md).)

## Clipped
A Clipped Cover, Top View A Clipped Cover, Bottom View 
## Nubbed
A Nubbed Cover, Top View A Nubbed Cover, Bottom View 

## Design
`.25 HU` is close to the height of covers purely due to a combination of divisibility and clearance concerns while trying to simultaneously
respect the amount of material used. Firstly, since a division of `.5 HU`
already exists naturally in Plaice (see [Units](/docs/design/Units.md)), that gives a starting candidate for the cover thickness. However,
there would be several problems with doing so — in particular, assemblies built out of Plaice components couldn't assume that a `1 HU`
gap between components (e.g: a bin inside a cubby) would suffice for clearance, because all of the involved components could have
(and should be allowed to have) covers on them. Consequently, the next nice divisor available is `.25 HU = 1.75 mm`. If we're working
with a typical "structural" printing profile, we can assume four `.4mm` perimeters in XY = `1.6 mm`, and roughly the same material thickness
for top and bottom solid layers. Since all other candidate divisors are smaller than `1.6 mm`, we have to pick `.25 HU` for nice out-of-the-box
slicer behavior. 

However, `1.75 mm` is not a multiple of `.1 mm`, which is the typical layer height employed when printing Plaice components. To accommodate this,
the de facto height of covers is rounded down to `1.7 mm`.

Covers also impact other components in the Plaice system, especially when a string of Plaice plates connected by slides is meant to be interrupted
by a different kind of Plaice component with a slide connector. In those cases, it's important to ensure that not only is there enough clearance
for covers to be inserted on adjacent plates, but also to ideally have the result be as visually seamless as possible. Some examples of this
are in Plaice [crosses and tees](/doc/components/CrossesAndTees.md) and [corner stacking caps](/docs/components/CornerStackingCaps.md)

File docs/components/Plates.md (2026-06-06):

# Plates

A 2x2 Plaice Plate An 8x8 Plaice Plate

The single most important Plaice component, plates give the rest of the system a structural base.
A plate consists of a `7mm` (`1 HU`) rectangular slab covered in an array of [sockets](/docs/design/Sockets.md)
spaced `21mm` ([`1 CU`](/docs/components/design/Units.md)) apart,
with opposing pairs of intruding and protruding [slides](/docs/design/SlideInterface.md) along the perimeter. Plates are so named because
they serve a similar purpose to the "baseplates" in Gridfinity and other similar systems, in that they
are a central component which all other components of the system can connect to, but the "base" prefix
is dropped to avoid the connotation of a fundamental placement or orientation.

## Printability modifications

Printable Plate Printable Plate, Corner View Printable Plate, Side View

The "printable" version of plates requires no slicer-generated supports to print, because the necessary supports are baked in
to the design. First, mouse ears were added to the design to protect corners and overhanging protruding slides
from warping while providing somewhat better bed adhesion for small plates. Then, for supports, two preforated-boundary
single-perimeter strips support both the intruding and protruding slides' overhangs at points where they are _concave up_,
with the strips more or less equidistant from the local minima there. This is done to minimize the impact that leftover
scarring from the preforations would have on the overall fitment of slides on plates.

### Suggested Support Removal Process

When removing the supports of a large number of printed Plaice plates, it's a good idea to have an easily-repeatable process
that can be worked into muscle memory. Here is one possible way of doing that:

#### Step 1. Peel Protrusion Supports
Step 1 Visual 

Locate the edge of one of the two-perimeter supports for the plate's protruding slides. With a pliers, grab and
pull upwards **slowly** to remove the supports along their preforations. Do the same for the other protruding slide,
and for the protruding corner support.

#### Step 2. Peel Intrusion Supports
Step 2 Visual 

Locate the edge of one of the two-perimeter supports for the plate's intruding slides. Perform the same kind of
operation as step 1 on these supports, and do it for both intruding slides. 

#### Step 3. Check For Partially-Removed Supports
Step 3 Visual 

Inspect the workpiece to verify that there are no partially-removed supports. If there are some, just grab hold
of what's left and again peel them away from their preforations slowly with the needle-nose pliers.

#### Step 4. Tear Off Intruding Corner Mouse Ear
Step 4 Visual

Grab hold of the mouse ear on the bottom of the plate near the intruding corner with your pliers as shown.
Feel free to rip the ear off **fast**, then carefully trim off any remaining material from the mouse ears
by grabbing hold of it with the pliers and twisting, which may need to be repeated depending on tearing
technique and the quality of the print's first layer.

#### Step 5. Tear Off Protruding Corner Brim
Step 5 Visual 

Grab hold of the brim at the intruding corner with your pliers as shown, and perform the same kind of process
as the previous step. Once again, feel free to rip **fast** and "trim" leftover pieces as needed. 

## ...Finish!
Finished Plate

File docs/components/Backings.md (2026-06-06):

# Backings

Clipped and Nubbed Backings

Several Plaice components (e.g: [gridfinity integration components](/docs/components/GridfinityIntegration.md), [opengrid integration components](/docs/components/OpenGridIntegration.md),
and [slide and glide bolt-ons](/docs/components/SlideAndGlideBoltOns.md)) are [bolt-on](/docs/design/BoltOnComponents.md) components which do not have their own [clipped or nubbed connectors](/docs/design/ClipInterface.md). They instead rely upon backings to provide connector functionality.

Both clipped and nubbed backings are similar to [clipped and nubbed covers](/docs/components/Covers.md) in that they have the same external dimensions, but they have different
holes and pockets for [M2 bolts](/docs/design/M2Bolts.md) reflecting their role as a supporting component rather than one that's externally visible.

## Clipped Backings

Clipped Backing Clipped Backing, Top View 

Clipped backings may be used to add clipped connectors to a bolt-on component using four M2 `6 mm` bolts and four captive M2 nuts at the corners of the bolt-on and this backing, respectively.
They are almost identical to clipped covers, but their bolt-holes go all the way through the component.

## Nubbed Backings

Nubbed Backing Nubbed Backing, Bottom View 

Nubbed backings may be used to add nubbed connectors to a bolt-on component using four M2 `4 mm` bolts and four captive M2 nuts at the corners of the bolt-on and this backing, respectively.
They are somewhat similar to nubbed covers, but captive nut channels have been added to the four corner connectors, and the pockets for bolt heads have been removed.

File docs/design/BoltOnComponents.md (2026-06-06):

# Bolt-On Components

A gridfinity bolt-on in the process of being secured to a clipped backing

Sometimes makes more sense to print a Plaice component out of multiple different parts
to bolt together. On the design side, a maker looking to [integrate](/docs/design/InterfacingAndRemixing.md) with the system may be using direct 3d modeling and find the prospect of providing
pieces with multiple different levels of clearances to be daunting. Alternatively, when printing, the required support geometry for a unified
part could require awkwardly-placed or hard-to-remove supports. 

Plaice encourages the use of bolt-on components for these scenarios when the component in question needs an array of
clipped or nubbed [connectors](/docs/design/ClipInterface.md), which are provided via [backings](/docs/components/Backings.md).
The bolt-on component may then be attached to the backing using [M2 hardware](/docs/design/M2Bolts.md). Multiple built-in components in Plaice adopt this pattern, e.g: 
[Gridfinity integration components](/docs/components/GridfinityIntegration.md), [OpenGrid integration components](/docs/components/OpenGridIntegration.md),
and [slide/glide bolt-ons](/docs/components/SlideAndGlideBoltOns.md).

## Design

To create a bolt-on component, all that's needed is an array of appropriate pockets and holes spaced identically to the [unit grid](/docs/design/Units.md)
carved into the component -- a square array with center-to-center spacings of `21 mm`. At each of those positions, there should be both an at least `2 mm` through-hole
(after printing -- slight oversizing is recommended) and a pocket to accommodate a M2 hex nut with around `1 HU` (`1.7 mm`) of material beyond the bottom of the pocket
to where the backing would go. The latter requirement ensures that required bolt lengths for assemblies follow [what is stated in the guide](/docs/design/M2Bolts.md), and so it helps to minimize
potential confusion around needing to source bolts of different lengths. While not required, it's recommended that the pocket
for M2 hex nuts is at least `2.0 mm` deep to prevent hardware from protruding, since the same pocket may be used for socket-head M2 bolts.
Finally, ensure that your component has appropriate [clearances](/docs/design/Clearances.md) built-in to allow it to tile cleanly on a unit grid with other components.

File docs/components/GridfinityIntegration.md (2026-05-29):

# Gridfinity Integration

A Gridfinity Baseplate Bolt-On A Gridfinity Bin Base Bolt-On

Plaice integrates with [Gridfinity](https://gridfinity.xyz/) bidirectionally, and Plaice assemblies can be treated as Gridfinity bins or as a place to mount Gridfinity baseplates.
Two Plaice [cell units](/docs/design/Units.md) are equivalent to one Gridfinity grid unit, and so the synchronizing length is `42mm`.

## Bolt-On Bin Bases

A Gridfinity Bin Base Bolt-On A Gridfinity Bin Base Bolt-On, Top View

To use Plaice assemblies as Gridfinity bins, the gridfinity "bin base" is a Plaice [bolt-on component](/docs/design/BoltOnComponents.md) consisting of a Gridfinity bin base with pockets and holes for
[M2 bolts](/docs/design/M2Bolts.md) and/or captive M2 nuts. It is meant to be secured to a [`2 CU x 2 CU`](/docs/design/Units.md) [backing](/docs/components/Backings.md).

## Bolt-On Baseplates

A Gridfinity Baseplate Bolt-On A Gridfinity Baseplate Bolt-On, Bottom View 

To attach Gridfinity baseplates to Plaice plates, the gridfinity "baseplate" is a Plaice bolt-on component for backings
of an even length and width in cell units. It has mostly the same geometry as an official Gridfinity baseplate, but with pockets and holes to allow
it to be a bolt-on component, and a different size for inserted magnets. To accommodate the required positioning of holes for Plaice bolt-ons,
the magnet pockets had to be reduced in size to accommodate `4 mm` diameter by `1 mm` height magnets instead of the more typical `6 mm` diameter
by `2 mm` height magnets employed in Gridfinity. Just like in Gridfinity, magnets may be secured with cyanoacrylate glue or similar.

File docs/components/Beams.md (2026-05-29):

# Beams

A Key-Access Beam, Bottom View A Thru Beam, Bottom View

Plaice beams are components which are commonly used as "legs" or "columns" of free-standing shelves.
They consist of a [`1 CU x 1 CU`](/docs/design/Units.md) base with a [clipped connector](/docs/design/ClipInterface.md)
embedded in a [socket](/docs/design/Sockets.md) and an optionally-tapered top which
can be `1 CU x 1 CU` (not tapered), `1 CU x 2 CU` (tapered along one direction), or `2 CU x 2 CU` (tapered along both
directions), and has nubbed connectors on top.

Tapered beams are largely helpful for minimizing deflection of [plates](/docs/components/Plates.md) mounted on top of them due
to the increased moment the taper gives against plate deflection. Their tapers are `.75 HU` in height
to ensure that `1 HU` of clearance in an assembly is enough to accomodate e.g: a cover on top of a plate
which is `1 HU` below the plate atop the beam. Just before the nubbed connectors, the taper also has
a `.25 HU` pad to provide visual seamlessness with any [nubbed covers](/docs/components/Covers.md) mounted to the bottom side
of the top plate. 

## M2 Bolt Integration Variants

Beams have a similar challenge to [thru-nubs](/docs/components/ThruNub.md) in that at least one of their nubbed connectors
doesn't have immediately apparent access to its "back side". However, for long beams, a similar solution would not apply.
Consequently, in Plaice, there are two different beam variants:

### Thru-Beams
A Thru Beam, Bottom View A Thru Beam, Bottom View

When the desired length of beam is short enough that standard-issue [M2 bolts](/docs/design/M2Bolts.md) can easily pass through the whole length and interface with
other components in a Plaice assembly, you might consider using a thru-beam. Generally speaking, that means lengths of
`6 HU` and lower.

### Hex-Key-Access-Beams

A Key-Access Beam A Key-Access Beam, Bottom View 

Hex-key access bolted beams carve a channel along the interior corner of the beam length which allows both
a M2 bolt and an M2 hex key to be inserted into the channel, and the M2 hex key to be turned at 75 degree
increments to eventually tighten or loosen a bolt. Unlike the other solutions, this type of beam
allows for large lengths, but also requires a beam which is at least `5 HU` in length.

## Printing Tips

A Key-Access Beam, Printed With Supports A Key-Access Beam, Printed With Supports, Bottom View

As is the case with all other Plaice components with sensitive geometry on both sides of any hypothetical print orientation along Z, when printing a beam, the nubbed connectors should be oriented downwards,
so that their printability modification can be applied. Additionally, since the top of the beam (bottom in print orientation) has a flat of cell-unit-multiple sizing, support structures should be added to
support that flat at the bottom of the print. None of the other surfaces on the underside of the print, like the nubbed connectors or their chamfers, should have generated supports -- it wastes filament, time, and just makes them more difficult to remove.

That said, the M2 nut channel near the top of the print should not need any supports, so feel free to add support blocking modifiers there. Finally, in the
case of the hex-key-access bolted beam, supports should be generated for the void where the hex key is inserted. 

Beam Bottom Support Removal, Step 1

When removing supports from the bottom, first remove the slicer-generated support structures and the mouse-ears on the nubs to yield something like the picture above.
Then, break the bridges between the nubbed connectors' central islands using a needle-nosed pliers.

Beam Bottom Support Removal, Step 2 Beam Bottom Support Removal, Step 3

From this state, removal of the key access-slot supports and a poke through the corner hole with a screwdriver or Allen key will result in something that looks like the pictures at the top of this article.

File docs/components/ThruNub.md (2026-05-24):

# Thru-Nubs

A Thru-nub, Side View A Thru-nub, Top View 

A Plaice thru-nub is essentially a clipped and a nubbed [plug](/docs/components/Plugs.md) fused onto the backs of one another, but with the usual M2 interface
replaced by a single thru-hole for a M2 bolt. 

They are used in a couple of different scenarios in Plaice, both starting with a [nubbed connector](/docs/design/ClipInterface.md) inserted into
one half of a Plaice [socket](/docs/design/Sockets.md).

From there, a [beam](/docs/components/Beams.md) may be attached using a thru-nub to cover the gap between the plate [socket](/docs/design/Sockets.md) and the beam's internal
socket with a clipped plug.

Or another Plaice [plate](/docs/components/Plates.md) can be stacked on top of the first one and secured with a clipped plug, yielding a thicker composite plate. 

# Printing

A Thru-nub right after printing A Thru-nub right after printing, Bottom View 

The "printable" modification of thru-nubs may be printed without supports or a brim, because it adds substantial first layer surface-area
via mouse-ears and bridges which connect the nubbed connector's central island to the corners.

Thru-Nub support removal, step 1

To remove the supports, first remove the mouse-ears to yield something like the above picture. Then, break the bridges
between the islands on the nubbed connector using a needle-nose pliers.

Thru-Nub support removal, step 2 Thru-Nub support removal, step 3

Once completed, the result will look like the pictures at the beginning of this article.

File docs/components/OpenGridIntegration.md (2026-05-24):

# OpenGrid Integration

An OpenGrid baseplate bolt-on An OpenGrid snap bolt-on

Plaice integrates with [OpenGrid](https://www.opengrid.world/) bidirectionally, with the ability to mount OpenGrid baseplates to Plaice [plates](/docs/components/Plates.md) and vice-versa.
Four Plaice [cell units](/docs/design/Units.md) are identical to three OpenGrid cell units, which means that the length required to synchronize
is `84mm`. 

## OpenGrid Snap Bolt-Ons
 An OpenGrid snap bolt-on An OpenGrid snap bolt-on, top view 

The "snap" bolt-on allows connecting a Plaice plate to an OpenGrid baseplate, and it consists of an array of OpenGrid snaps meant to be bolted on (TODO: link) to a
`4 CU x 4 CU` backing (TODO: link). 

## Baseplates
An OpenGrid baseplate bolt-on An OpenGrid baseplate bolt-on, bottom view 

The "baseplate" is a bolt-on to a `4 CU x 4 CU` Plaice backing which adds an OpenGrid baseplate.

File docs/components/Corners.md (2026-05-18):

# Corners

A Corner A Corner, Back View

A Plaice corner connects two Plaice [plates](/doc/components/Plates.md) at a right angle with a paired set of intruding and protruding [slides](/doc/design/SlideInterface.md). In that respect,
it is analogous to [crosses and tees](/doc/components/CrossesAndTees.md), but for just two plates. Similarly, using a corner or using one of a cross or a tee
to orient two plates at identical right angles will result in identical placement (center of the next plate is `1.5 HU` from the logical
cell boundary of the first plate.)

Unlike crosses and tees, corners have a chamfer on their exterior, which is `.75 HU` in length. This length is chosen to match the chamfer
on the inner portion of the corner, both for aesthetic purposes and because it is the longest possible chamfer length which is both
still a multiple of `.25 HU` (the smallest employed by the system), and leaves at least _some_ completely horizontal overlap with [stacking lips](/doc/components/StackingLips.md). 

## Printability modification

A Corner, just after printing

Corners have a printability modification for especially long corner connectors to help stabilize them from toppling
over on the build plate, consisting simply of a partial brim around the exterior of the corner.

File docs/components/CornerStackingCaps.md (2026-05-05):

# Corner Stacking Caps

A Corner Stacking Cap, Thick Variant A Corner Stacking Cap, Thin Variant 

Plaice corner stacking caps perform an analogous function to [corner caps](/docs/components/CornerCaps.md) in Plaice, but for the top corners of open-top boxes.
Both designs for corner stacking caps allow stacking other Plaice boxes of identical footprint on top, but differing in
their suitability for boxes based on size.

## "Thin" Variant
A Corner Stacking Cap, Thin Variant A Corner Stacking Cap, Thin Variant, Bottom View 

For small boxes, the "thin" variant effectively just continues a [stacking lip](/docs/components/StackingLips.md) around the corner of a box, and as a result,
it is unsuitable for large boxes or large deformations. 

## "Thick" Variant
A Corner Stacking Cap, Thick Variant A Corner Stacking Cap, Thick Variant, Bottom View

For larger boxes or more weight, the "thick" variant instead adds a platform spanning the corner which has a stub [socket](/docs/components/Sockets.md) on it.
The stub socket is intended to be used with [stacking pegs](/docs/components/StackingPeg.md) as feet for any boxes above it, since the stub
socket provides a stable, predictable place for the corners of large or heavy boxes to seat. The support for the platform
is fairly bulky for the sake of strength, but does taper towards a single cover's thickness at the bottom. Overall, the platform
is [`1 CU`](/docs/design/Units.md) in height, and should be assumed to take up an entire `1 CU x 1 CU x 1 CU` block for the sake of assemblies.

## Printing Tips
A Corner Stacking Cap, Thin Variant, just after printing A Corner Stacking Cap, Thick Variant, just after printing

Print both variants with supports for the sake of the bottom flats of the stub slides.

## Chirality

Both variants of corner stacking caps are chiral, meaning that they are not equivalent to their mirror images. In practice, this means that when assembling Plaice boxes,
depending on the orientation of the plates making up the walls of the box, either with protruding slides oriented counterclockwise or clockwise, you will need to print
regular-variant corner stacking caps or their mirrored variants, respectively. See [the recipe for stacking boxes](/docs/recipes/StackingBoxes.md) for an example.

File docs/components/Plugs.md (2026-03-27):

# Plugs (Clipped and Nubbed)

Plugs, Clipped and Nubbed, Bottom Views Plugs, Clipped and Nubbed, Top Views

Plaice plugs may be used to fill the remainder of a Plaice [socket](/docs/design/Sockets.md) where an opposing [connector](/docs/design/ClipInterface.md) (clipped or nubbed)
is already present.

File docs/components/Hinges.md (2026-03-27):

# Hinges

A Hinge

Hinges allow Plaice components to rotate around a central axis, and allow many different constructions.

Standard Plaice hinges are designed to align with the relative offset between [slides](/docs/design/SlideInterface.md) obtained with a [corner](/docs/components/Corners.md)
when oriented at 90 degrees from straight, and to continue with [cell-unit](/docs/design/Units.md) alignment when held straight.

## Printing
A Hinge, just after printing

Hinges must be printed with supports for the protruding and intruding slides, but the connection between
the hinge halves is print-in-place and requires no supports.

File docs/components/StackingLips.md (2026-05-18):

# Stacking Lips

Stacking Lips, Intruding and Protruding

A Plaice stacking lip is a terminal [slide](/docs/design/SlideInterface.md) which can be used to terminate a slide (here assumed to be directed vertically)
with geometry which mates nicely with the chamfered geometry of [corners](/docs/components/Corners.md).

Stacking lips may be used to construct stackable boxes out of Plaice components, but they are not generally suitable
for large stacking boxes by themselves, since the deflection of Plaice [plates](/docs/components/Plates.md) making up the walls may be too high
for stacked boxes to seat properly. Consequently, for larger boxes, it is recommended to use the "thick" variant
of [corner stacking caps](/docs/components/CornerStackingCaps.md) to ensure that at least the corners of boxes are always supported.
See the [stacking boxes recipe](/docs/recipes/StackingBoxes.md) for more information.

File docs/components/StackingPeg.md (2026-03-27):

# Stacking Pegs

A Stacking Peg, Bottom View A Stacking Peg, Side View 

A stacking peg is effectively a stub version of a Plaice [nubbed connector](/docs/design/ClipInterface.md) with smoothed geometry which makes it
more hand-friendly while also retaining the geometry needed to seat into a thick [corner stacking cap](/docs/design/CornerStackingCaps.md)

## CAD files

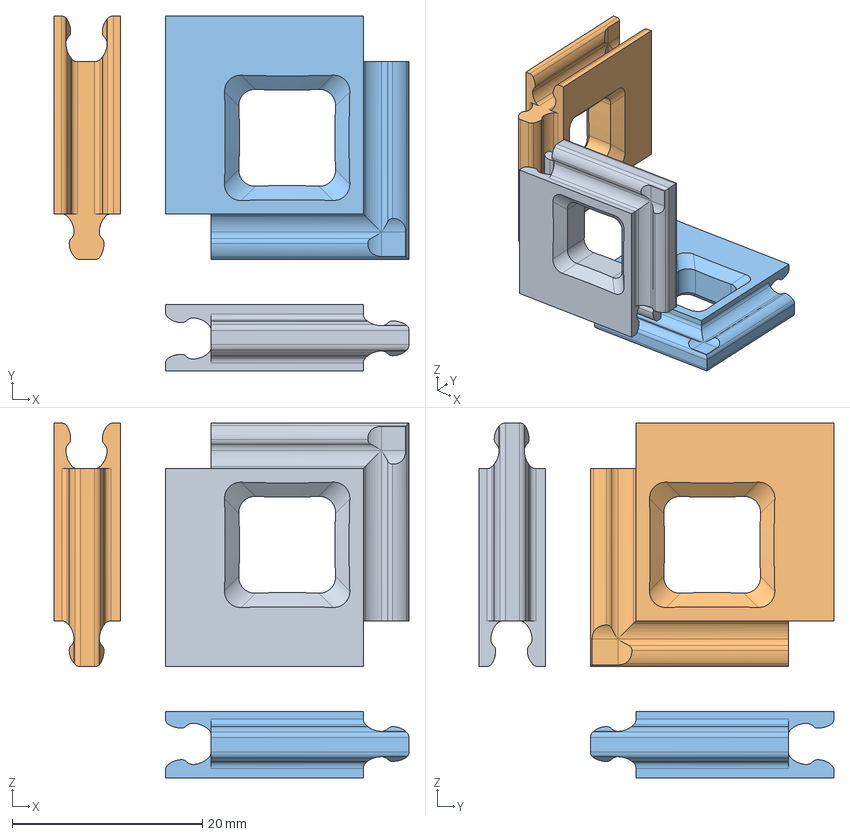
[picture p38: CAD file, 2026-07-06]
cad/corner_assemblytest.FCStd
37.3 x 37.3 x 37.3 mm
plate006
plate007
plate008

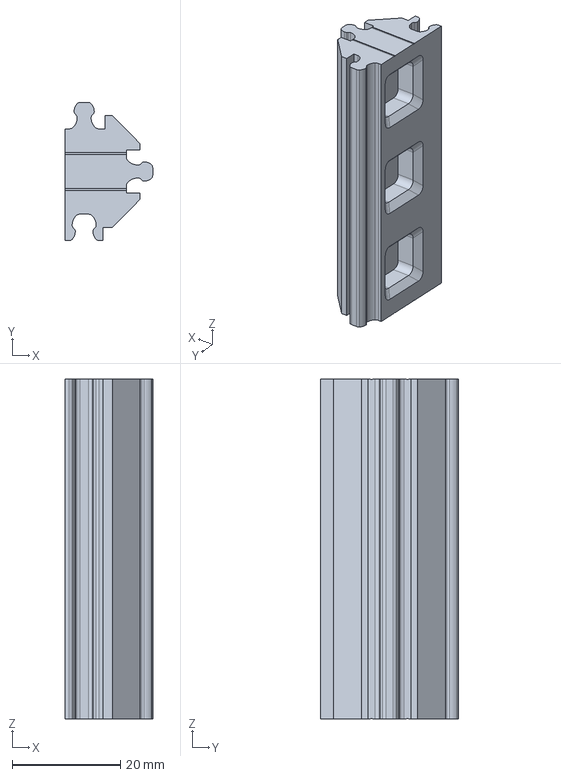
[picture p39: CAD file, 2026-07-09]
cad/tee_glide_protruding.FCStd
16.2 x 25.5 x 62.8 mm

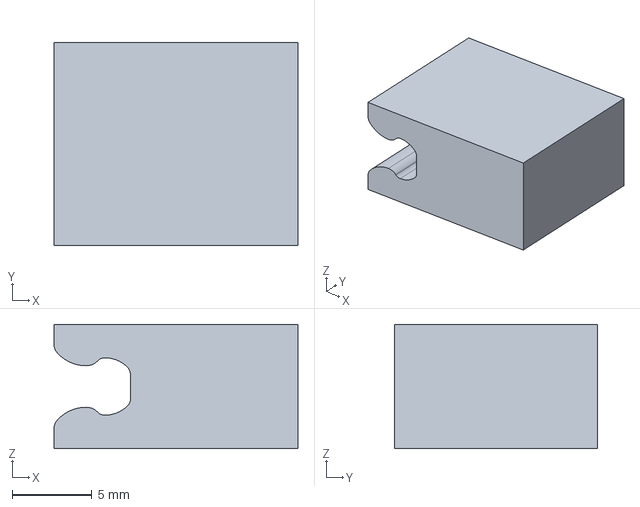
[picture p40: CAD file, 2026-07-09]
cad/slide_protruding_raw.FCStd
15.3 x 12.7 x 7.80 mm

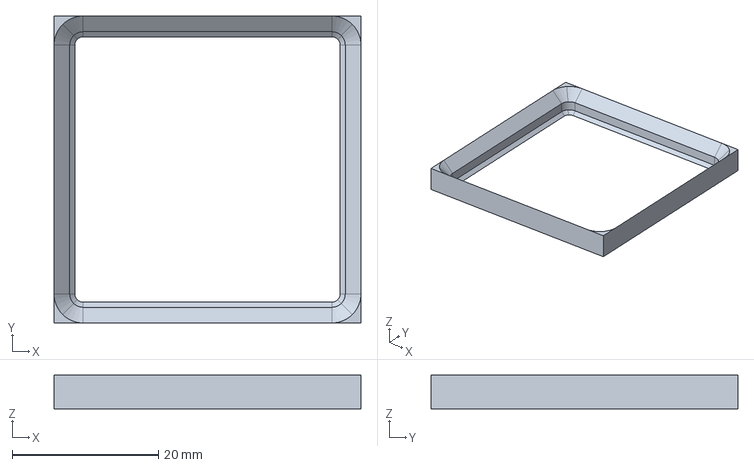
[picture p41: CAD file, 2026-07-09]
cad/gridfinityborder.FCStd
42.0 x 42.0 x 4.65 mm

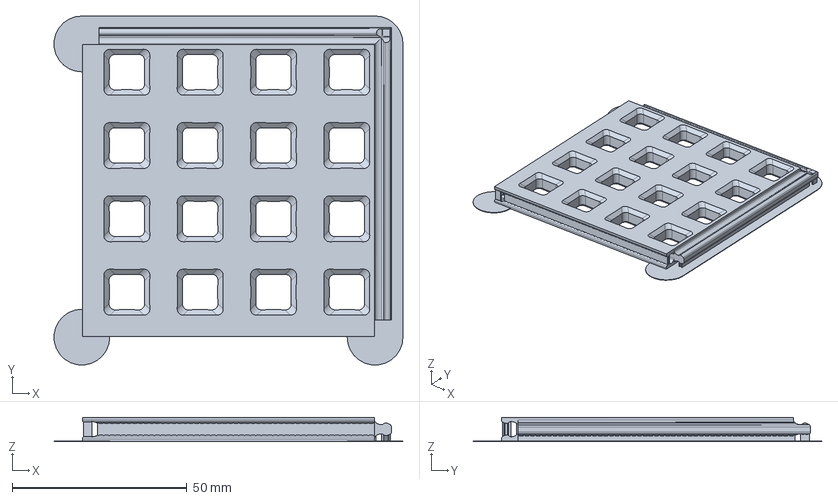
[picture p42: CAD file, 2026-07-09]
cad/plate_printable.FCStd
100.0 x 100.0 x 7.00 mm

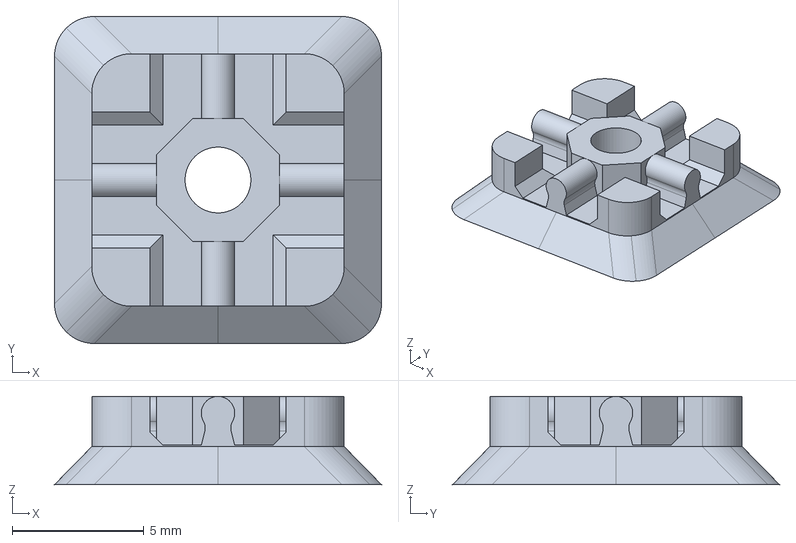
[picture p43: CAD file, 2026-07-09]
cad/plug_nubbed_standalone.FCStd
12.4 x 12.4 x 3.35 mm

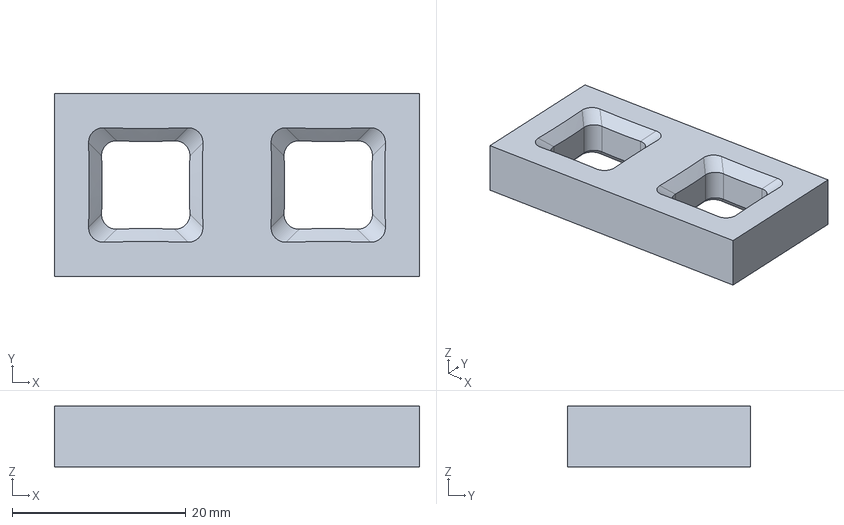
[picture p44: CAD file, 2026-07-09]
cad/plate_bare_xy.FCStd
42.0 x 21.0 x 7.00 mm

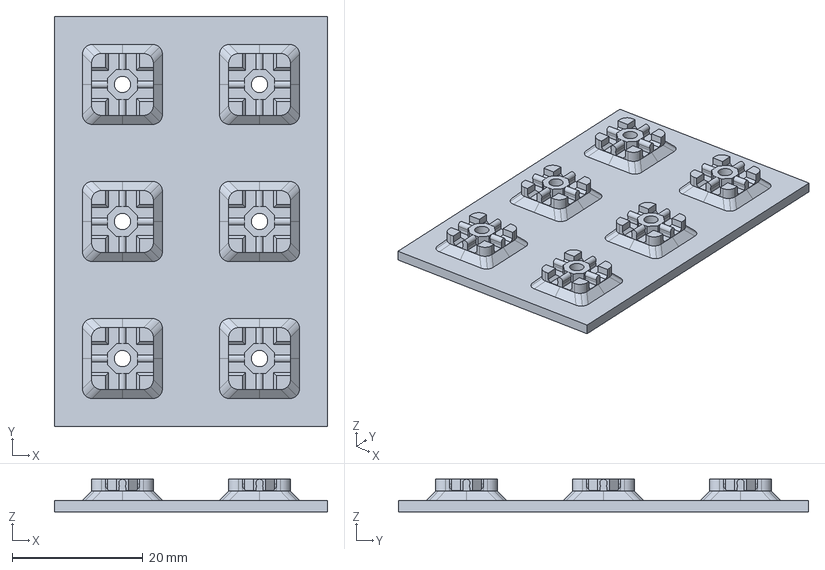
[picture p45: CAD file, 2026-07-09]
cad/cover_nubbed_base.FCStd
41.8 x 62.8 x 4.99 mm

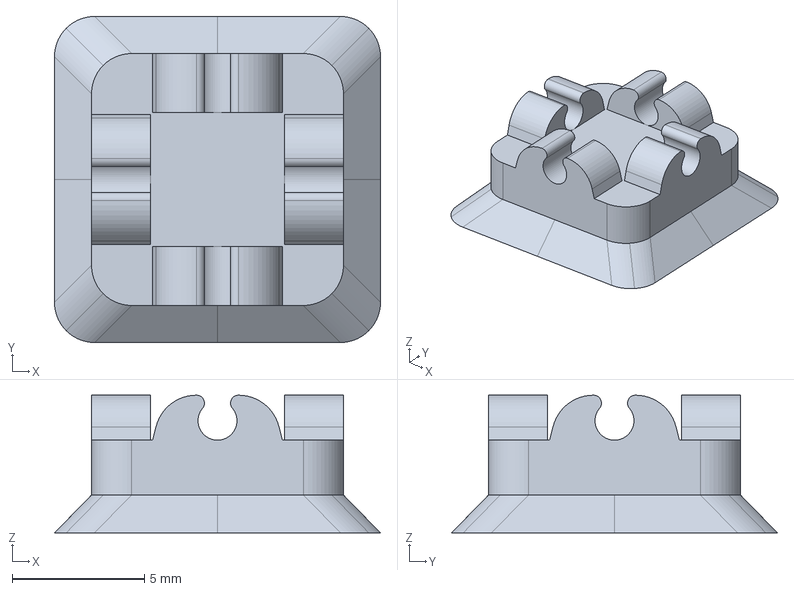
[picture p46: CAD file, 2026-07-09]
cad/plug_clipped_bare.FCStd
12.3 x 12.3 x 5.20 mm

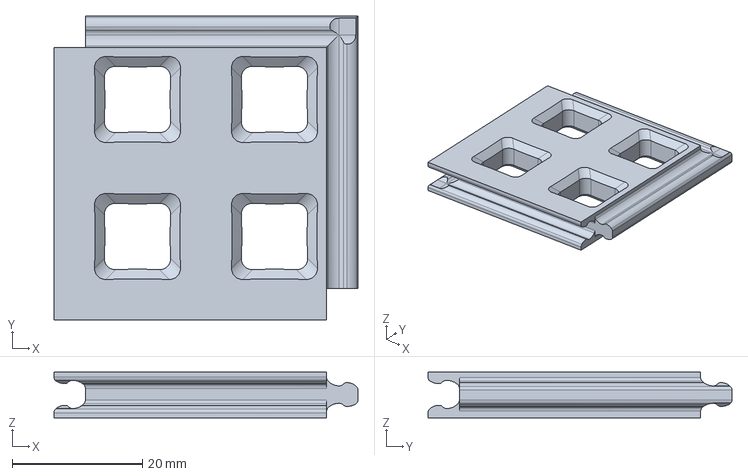
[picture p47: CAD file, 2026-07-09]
cad/plate.FCStd
46.6 x 46.6 x 7.00 mm

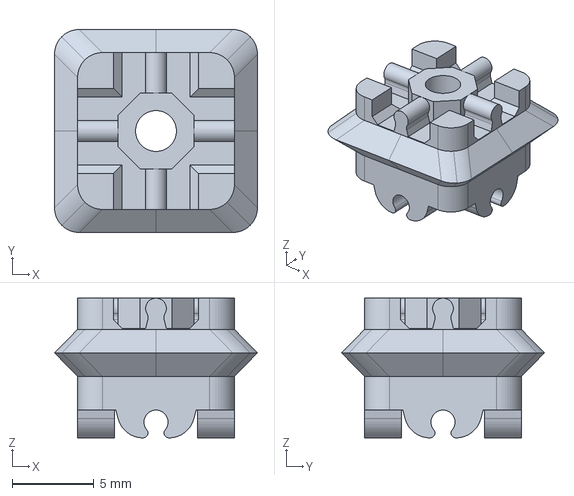
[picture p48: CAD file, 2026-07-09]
cad/thrunub.FCStd
12.4 x 12.4 x 8.55 mm

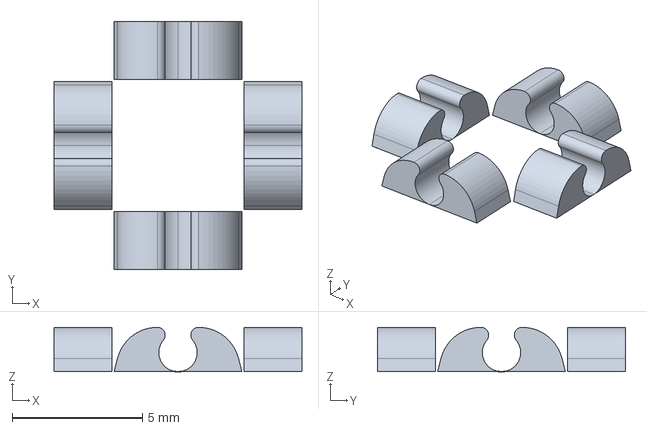
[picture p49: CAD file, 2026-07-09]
cad/connector_clipped.FCStd
9.51 x 9.51 x 1.70 mm

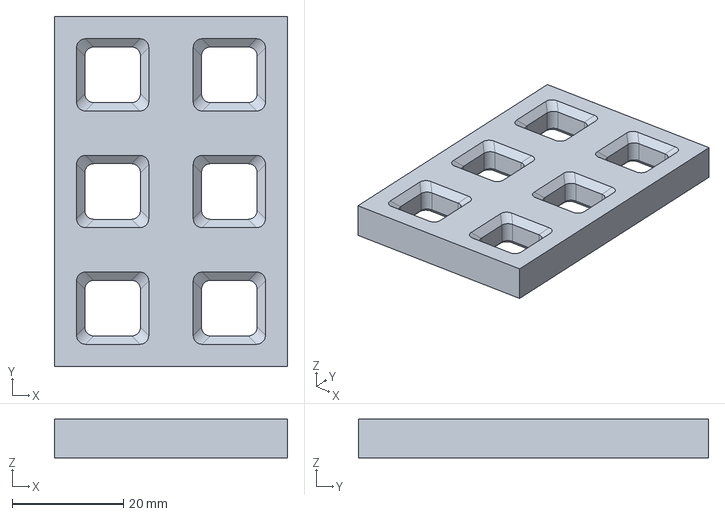
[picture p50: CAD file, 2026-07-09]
cad/plate_bare.FCStd
42.0 x 63.0 x 7.00 mm

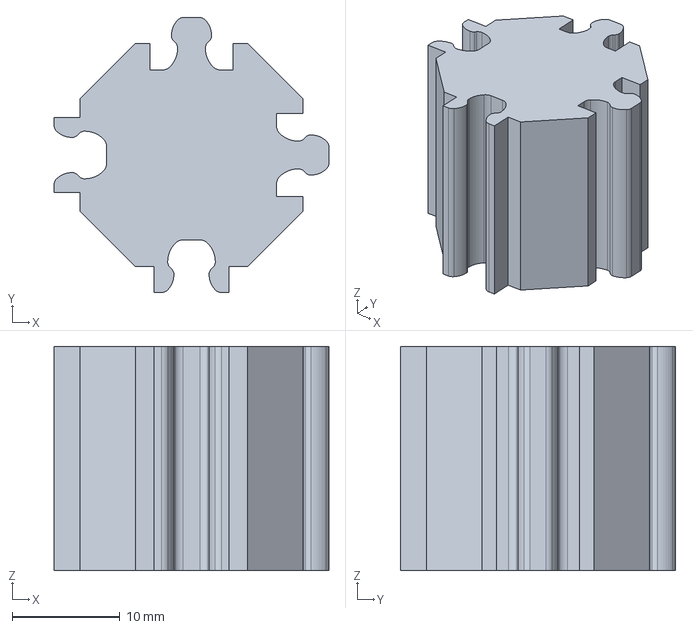
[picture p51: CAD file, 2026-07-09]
cad/cross_slide.FCStd
25.5 x 25.5 x 20.8 mm

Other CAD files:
cad/connector_interface.FCStd
cad/sheet.FCStd
cad/slide_interface.FCStd
cad/tee_slide_protruding.FCStd
cad/backing_clipped.FCStd
cad/backing_nubbed.FCStd
cad/beam.FCStd
cad/beam_bolted_base_printable.FCStd
cad/beam_bolted_keyaccess_printable.FCStd
cad/beam_printable.FCStd
cad/beam_thru_printable.FCStd
cad/corner.FCStd
cad/corner_printable.FCStd
cad/cornercap_inside.FCStd
cad/cornercap_outside.FCStd
cad/cornerstackingcap.FCStd
cad/cornerstackingcap_thin.FCStd
cad/cover_clipped.FCStd
cad/cover_nubbed.FCStd
cad/cross_glide.FCStd
cad/glidebolton_intruding.FCStd
cad/glidebolton_protruding.FCStd
cad/gridfinitybaseplatebolton.FCStd
cad/gridfinitybinbasebolton.FCStd
cad/hinge.FCStd
cad/lasercut.FCStd
cad/manualrouterjigs.FCStd
cad/nubmouseears.FCStd
cad/nubmouseears_array.FCStd
cad/opengridbaseplatebolton.FCStd
cad/opengridborder.FCStd
cad/opengridfundamentalunit.FCStd
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

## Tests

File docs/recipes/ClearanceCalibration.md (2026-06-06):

# Clearance Calibration
Two plates slid together

When getting started with Plaice, it's important to understand your 3d printer's accuracy in order
to appropriately calibrate the [clearance multiplier](/docs/design/Clearances.md) to be applied to
components. By doing so, Plaice assemblies will be much easier to construct and/or more structurally
"tight". 

## Ingredients

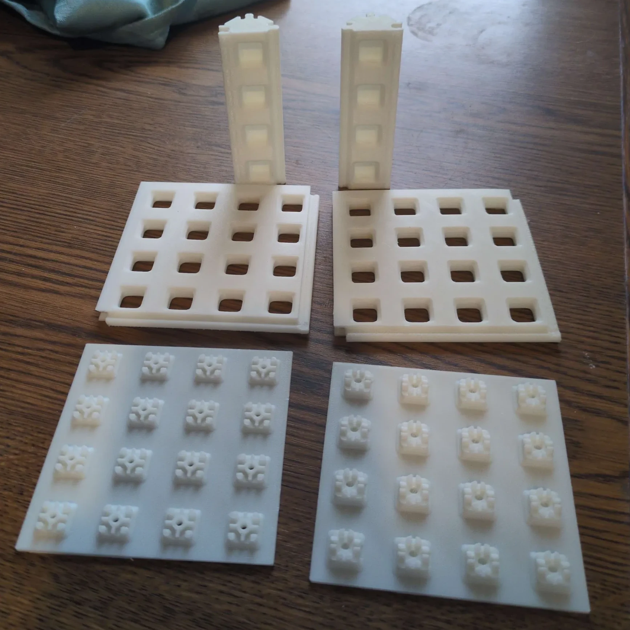
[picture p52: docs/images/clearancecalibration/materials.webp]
Required materials


- 2 `4 CU x 4 CU` Plates
- 1 `4 CU x 4 CU` Nubbed Cover
- 1 `4 CU x 4 CU` Clipped Cover
- 2 `4 CU` Protruding Tees

## General Guidance

This recipe has multiple different sections, each of which tests the fitment of a pairing of Plaice
components. You should start with an estimated clearance level for your printer in mind based
on experience (if you have used your printer substantially), or to simply start by trying the loosest
possible clearance level and working down from there (so long as you can physically fit components together,
even at a higher clearance level, they'll still be usable in future assemblies involving components
at a smaller level). The intent is that you will iterate these tests, adjusting the chosen clearance
level based upon guidelines given in each test, with some amount of room for individual preferences.

Strictly speaking, when trying to derive a candidate clearance level, it may be advantageous to
_temporarily_ run the tests with smaller-dimensioned components (e.g: `2 CU` instead of values of
`4 CU`) -- however, it's important to understand that these trial runs do not constitute complete
calibration, since e.g: some `2 CU x 2 CU` connector tests may not catch a small rotational skew
which would make a `4 CU x 4 CU` connector test fail.

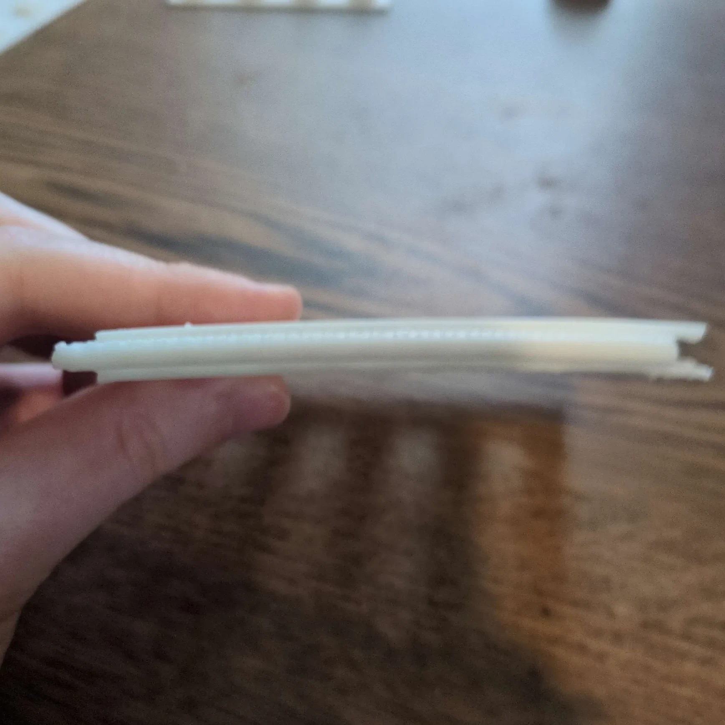
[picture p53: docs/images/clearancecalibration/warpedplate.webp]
A warped plate


Additionally, you should generally only perform these calibration steps after you've otherwise
optimized the print quality via slicer settings, printer settings, filament drying, temperature
stabilization, etc. If, for example, your plates are coming off the printer warped, it's pointless
to try to pursue clearance calibration before you first fix the warping issue by e.g: eliminating
drafts, adding a brim, making sure that your heatbed provides consistent heating, etc. etc.

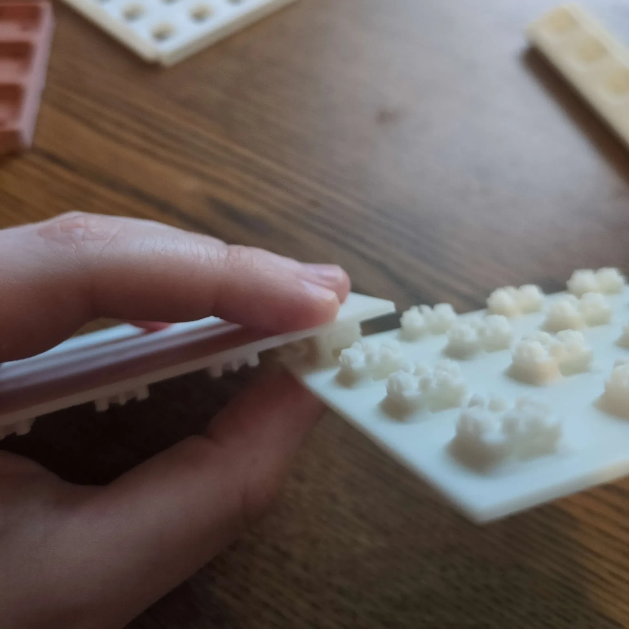
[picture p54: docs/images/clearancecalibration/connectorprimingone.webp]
Clip priming, clip one
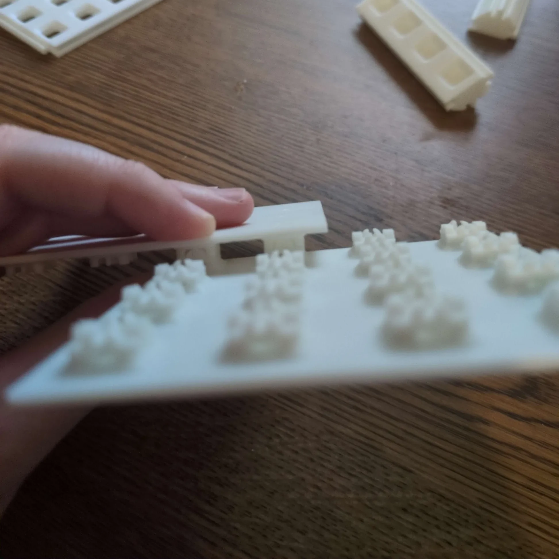
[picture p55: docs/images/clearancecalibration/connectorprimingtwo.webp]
Clip priming, a second clip
 

When testing fitment of [clipped and nubbed connectors](/docs/design/ClipInterface.md), be aware
that clipped connectors will be **much tougher** to connect the first time than subsequent
connections, to the point where you will probably want to individually "prime" clipped connectors via
an initial connection to a nubbed connector. A pro-tip for doing this more effectively
in general is to print a `1 CU x 1 CU` footprint [beam](/docs/components/Beams.md) to
use as a "clip priming tool" with the nubbed end, but this is not strictly required
to perform these calibration steps.

Finally, similar priming steps should be performed for [slide connections](/docs/design/SlideInterface.md) — after printing something with
a slide connector, swipe another slide-connector component over each of the protruding and intruding slides a few times. Doing
so ensures that blemishes and surface roughness left behind by any supports get somewhat smoothed out, resulting in a more
accurate finished piece.

## Clipped and Nubbed Covers Onto A Plate
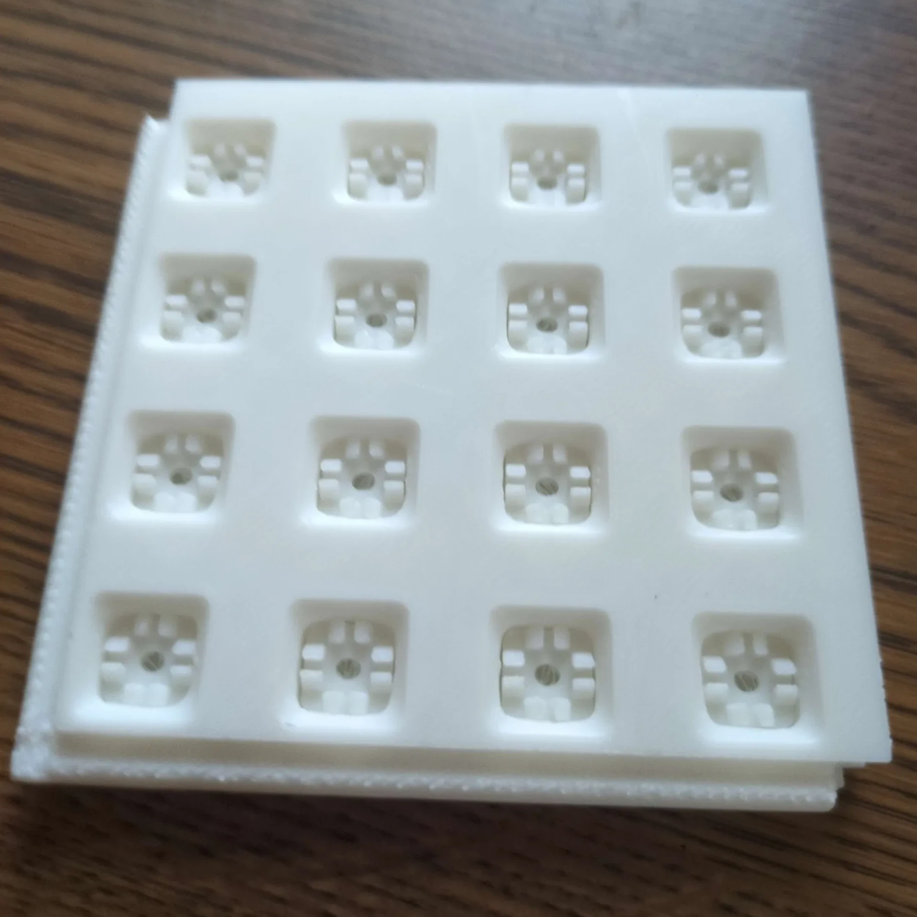
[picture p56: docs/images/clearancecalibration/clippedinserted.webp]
A clipped cover inserted into a plate
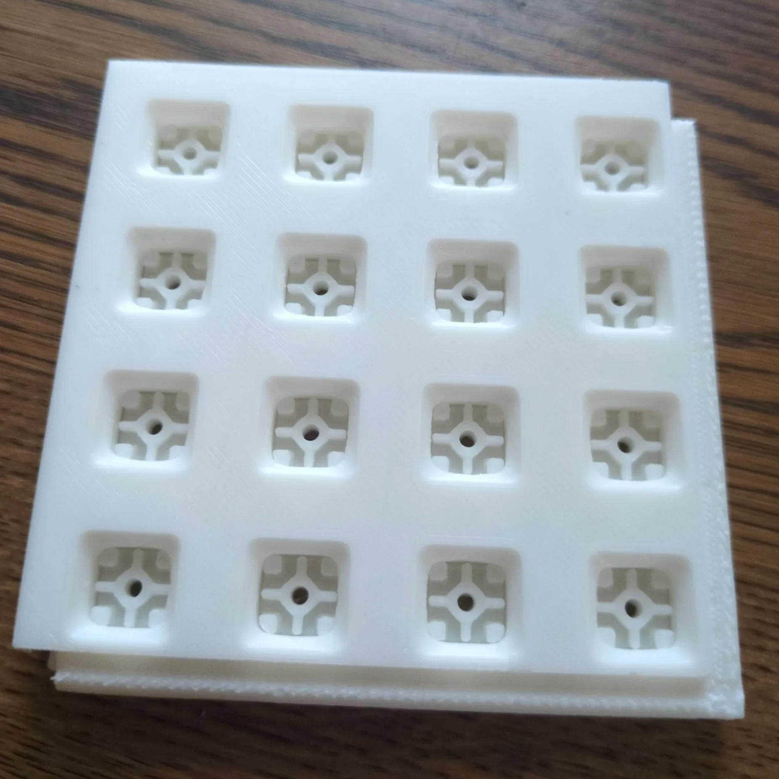
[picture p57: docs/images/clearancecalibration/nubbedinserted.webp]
A nubbed cover inserted into a plate
 

Take one of the two plates and the clipped cover, and try inserting the clipped connectors fully into
the [sockets](/docs/design/Sockets.md) of the plate. Verify that the top of the cover sits flush with the surface of the plate,
and that the process of insertion is easy enough for something that you'd be willing to do a lot. Perform the same verification steps
with the nubbed cover.

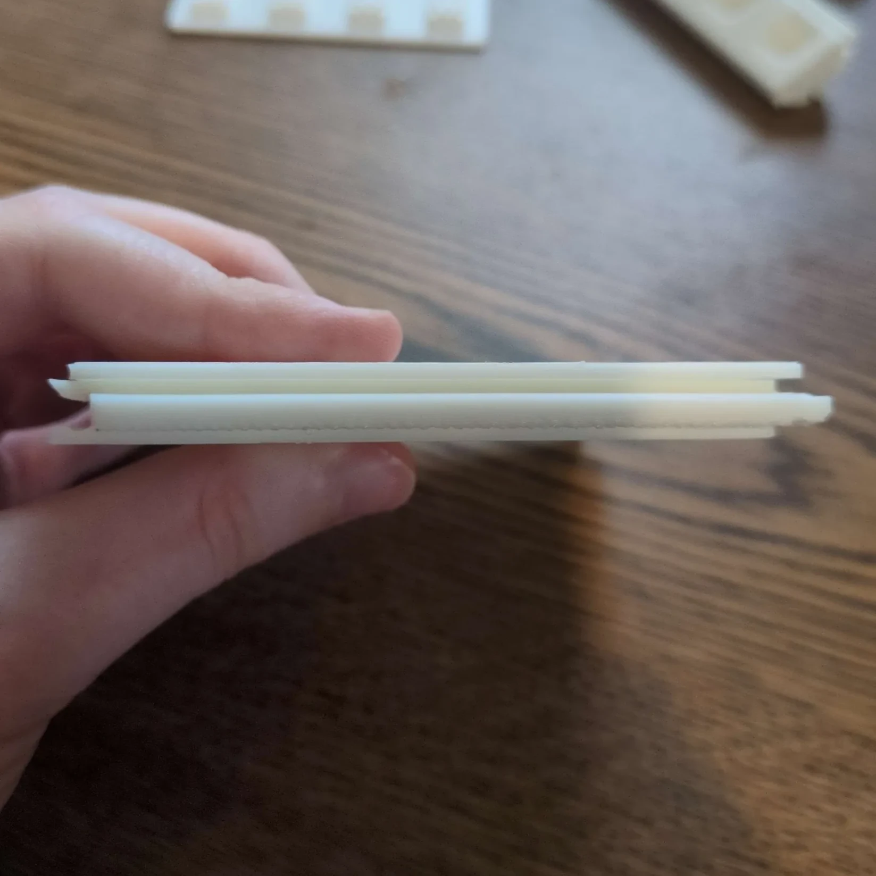
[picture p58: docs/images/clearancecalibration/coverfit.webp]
A cover, flush with the plate
 

## Clipped and Nubbed Covers Sandwiching A Plate
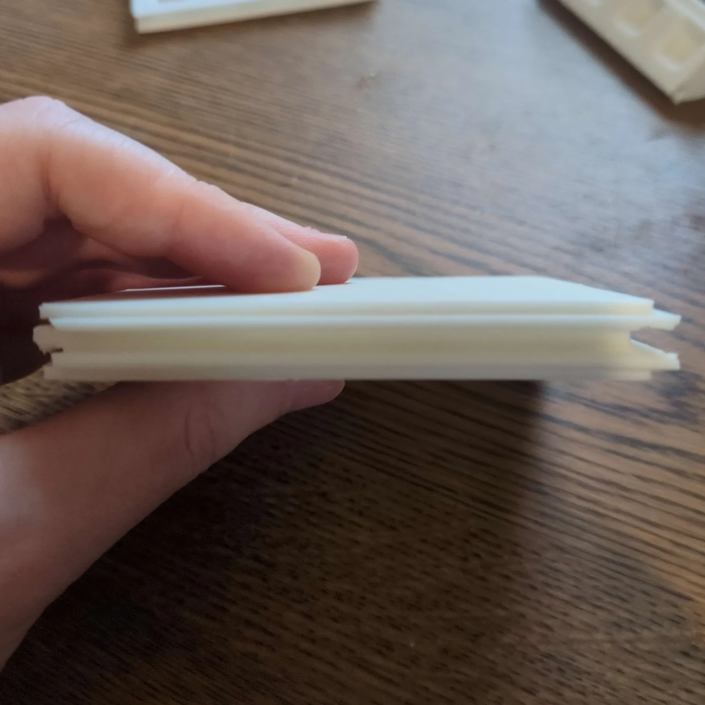
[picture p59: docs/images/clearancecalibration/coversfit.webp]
Covers snapped through a plate
 

Take a plate and push a clipped cover into it just like in the previous test, and from there, snap a nubbed cover
onto the clips which are now embedded in the plate's sockets. You may need to apply pressure at different
parts of the plate, bit by bit to fully secure the two covers. Verify that both covers are flush with the surfaces of the plate.

## Plate Sliding Test
Two plates slid together 

Take both plates and test all four slide connectors of each by sliding the other plate on. Hold just one
of the plates vertical, and verify that the unsupported plate doesn't slide off. Also verify that the resistance
during assembly is low enough for something that you'd be willing to do a lot.

## Tee Sliding Test
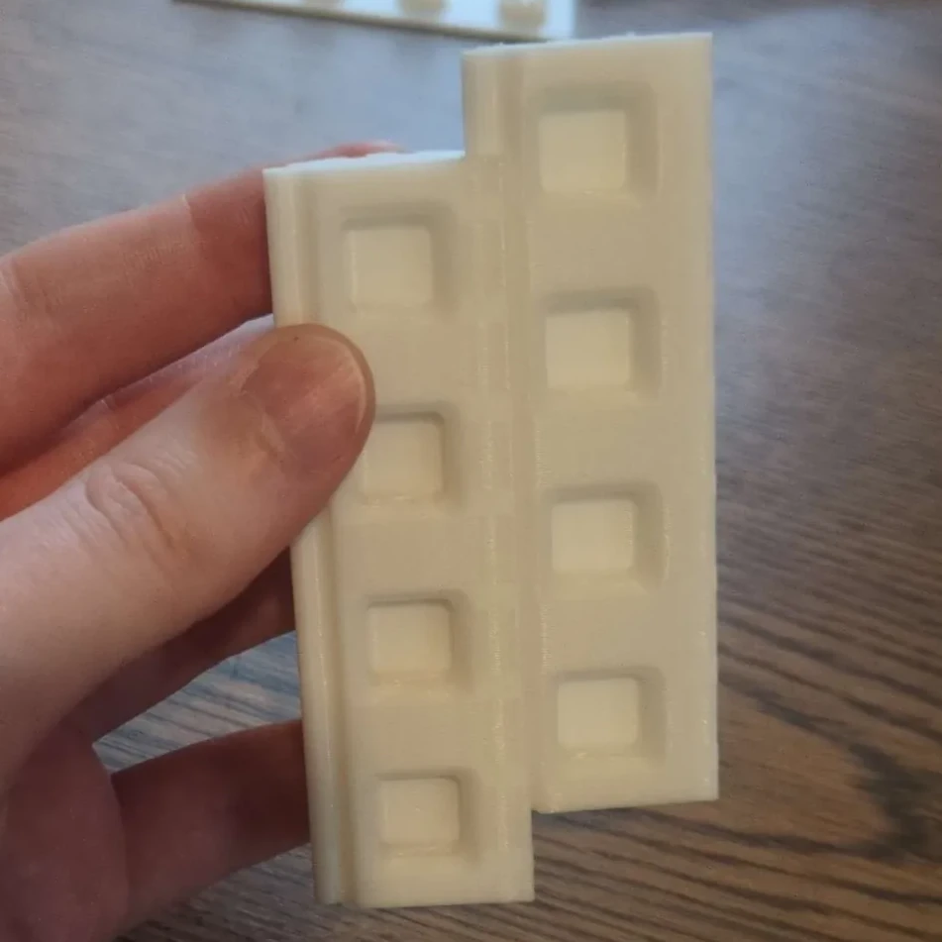
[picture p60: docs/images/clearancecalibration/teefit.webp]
Two tees slid together
 

Take both tees and perform the exact same kind of test as the one you performed for plates. However, don't
worry too much if the tees slide off of each other -- since printers tend to be more accurate in XY anyway,
the plate test is more critical for determining the clearance level, and so this test simply provides
an additional diagnostic.

## Plate-Tee Sliding Test
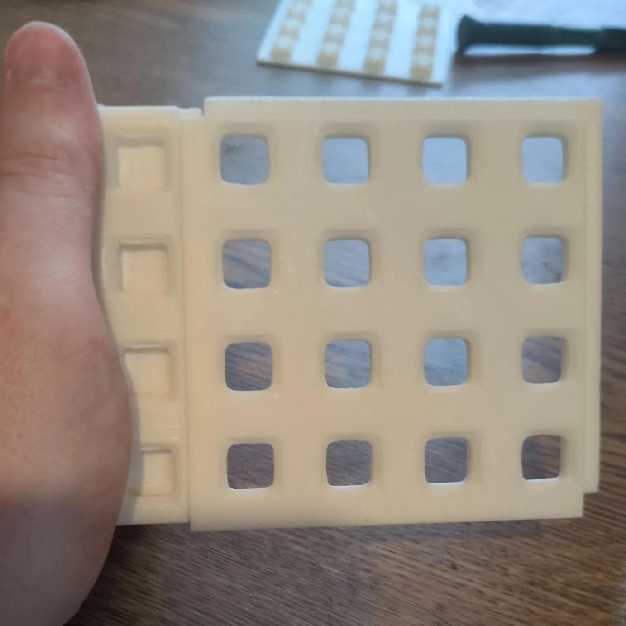
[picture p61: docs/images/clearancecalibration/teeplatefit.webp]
A plate and a tee slid together
 

Similar to the above two tests, but with a plate and a tee, and the plate unsupported. Unlike the previous test,
this test _is_ more critical for determining the clearance level, since it helps ensure fitment between slides
which are printed in different orientations. Additionally, using this test and the two previous ones, you can
get a rough idea of what your printer's error profile looks like for slides printed in different orientations,
which can in turn help with manually tuning CAD parameters (advanced users), or filing issues and/or asking
questions related to slide fitment with an appropriate level of detail. 

## Cover-Tee Test
Preparation A clipped cover partially inserted into a tee's stub sockets 

Take a clipped cover and a tee, and verify that four of the clipped connectors can be fully inserted into the stub sockets of the tee, with
the placement resulting in a flush alignment. A loose fit is perfectly fine here.

## ...Finished!

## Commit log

2026-03-19 CrossesAndTees.md - mention printability
2026-03-19 Update Plates.md (printability)
2026-03-24 Update Beams.md
    Add sample image
2026-03-24 Add images/hinge
2026-03-24 Add plate image
2026-03-24 Embed Images In Hinges.md
2026-03-24 Embed Images In Plates.md
2026-03-25 Create images/plate
2026-03-25 Plate support removal images
2026-03-25 Add OpenGrid mount support removal images
2026-03-25 Add thru-nub printability mod pics
2026-03-25 Add corner printability mod picture
2026-03-25 Update Beams.md with printing information
2026-03-25 Printing tips -> OpenGridIntegration.md
2026-03-25 Update wording on printing section of Beams.md
2026-03-25 Printability pics -> ThruNub.md
2026-03-25 Update Plates.md with support removal guide
2026-03-25 Printability image -> Corners.md
2026-03-25 Printability image -> CrossesAndTees.md
2026-03-25 Printed image -> CornerCaps.md
2026-03-25 Printed images -> CornerStackingCaps.md
2026-03-25 Printed images -> Hinges.md
2026-03-27 Add plaice socket image
2026-03-27 Add plaice socket side image
2026-03-27 Images -> Sockets.md
2026-03-27 Links -> Hinges.md
2026-03-27 Links -> Plates.md
2026-03-29 Links -> GlueTogetherComponents.md
2026-03-29 Links -> Sockets.md
2026-03-30 Add glueon and largeplate images
2026-03-30 Image -> GlueTogetherComponents.md
2026-03-30 Second image -> Plates.md
2026-03-30 Add stacked plate image
2026-03-30 Stacked plates image -> Units.md
2026-03-30 Stacked plates image -> SlideInterface.md
2026-04-13 Print corrections -> Clearances.md
2026-05-26 Bolt-on component reference -> InterfacingAndRemixing.md
2026-05-27 Add clearance calibration images
2026-05-29 Clearance calibration -> recipes/Index.md
2026-05-29 Update Socket (1.01).md
    Wording changes, switched order of sections
2026-05-29 Update BoltOnComponents (litleg 1.01) .md
    minimal phrase edits
2026-05-30 Update Plates (match to recipe guide format).md
    changed the step labels for consistency with the recipe step format
2026-06-06 Clarify parts of description in Sockets.md
2026-06-06 Small phrasing correction -> BoltOnComponents.md
2026-06-07 Update printability wording -> CrossesAndTees.md
2026-06-08 Print correction clearances -> Sockets.md
2026-06-08 Add XY socket image
2026-06-08 XY image -> sockets.md
2026-07-01 Add CAD files
    [bareclippedplug.FCStd, bareplate.FCStd, beam.FCStd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]
2026-07-01 Attempt correction of FCStd files
    [bareclippedplug.FCStd, bareplate.FCStd, beam.FCStd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]
2026-07-01 Another attempt to fix, including sketch .brps
    [bareclippedplug.FCStd, bareplate.FCStd, beam.FCStd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]
2026-07-01 Yet another attempt -- keeping binder BREPs, but removing common features
    [bareclippedplug.FCStd, bareplate.FCStd, beam.FCStd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]
2026-07-01 Give up on reducing size through pre-commit hook, upload raw FCStd
    [bareclippedplug.FCStd, bareplate.FCStd, beam.FCStd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]
2026-07-03 Add model export macro, remove old corner cap
    [cornercap.FCStd]
2026-07-06 Mass-update CAD model names, tested export script
    [backing_clipped.FCStd, backing_nubbed.FCStd, bareclippedplug.FCStd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]
2026-07-09 Prepare for launch, description export script
    [connector_clipped.FCStd, connector_interface.FCStd, corner.FCStd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]
